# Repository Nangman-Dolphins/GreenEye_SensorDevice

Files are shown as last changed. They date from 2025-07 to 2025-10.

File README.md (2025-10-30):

# GreenEye 원예/화훼용 스마트 센서 단말기 (ESP32-CAM)

본 레포지토리는 ESP32-CAM을 기반으로 하는, 원예 및 화훼 환경 모니터링용 센서 단말기 펌웨어다. 이 장치는 화분이나 재배지의 환경 및 토양 데이터를 정밀하게 수집하고, 식물의 생장 상태 이미지를 촬영하여 MQTT 브로커를 통해 중앙 제어 장치(CCU)로 전송하도록 설계되었다. CCU로 전송된 데이터는 시계열 분석 및 인공지능(AI) 이미지 패턴 인식을 통해 식물의 현재 상태를 정밀하게 판단하고 관리하는 데 사용된다.

## 주요 기능

* **다중 센서 데이터 수집:**
    * **공중 환경:** 주변 온도, 습도 (AHT20)
    * **광량:** 작물 생장에 유효한 조도 (BH1750/GY-302)
    * **토양 상태:** 토양 온도, 토양 수분(함수율), 토양 전기 전도도(EC) (ADS1015 ADC 경유)
    * **장치 상태:** 배터리 잔량 (ADS1015 ADC 경유)
* **식물 생장 이미지 캡처:**
    * ESP32-CAM을 사용하여 설정된 주기(전원 모드별 상이)로 식물 이미지를 촬영하고, Base64로 인코딩하여 MQTT로 전송한다.
* **MQTT 양방향 통신:**
    * 수집된 모든 데이터를 JSON 형식으로 MQTT 브로커에 발행(publish)한다.
    * CCU로부터 설정 변경(전원 모드, 야간 모드 등) 및 실시간 데이터 요청 명령을 구독(subscribe)하여 원격으로 장치를 제어할 수 있다.
* **듀얼 모드 작동 (저전력/설정):**
    * **일반 모드 (Normal Mode):** 평상시 작동 모드. 설정된 주기에 따라 센서 측정, 데이터 전송 후 즉시 Deep Sleep 모드로 진입하여 배터리 소모를 최소화한다.
    * **설정 모드 (Setup Mode):** 장치 설치 시 사용하는 모드. WiFi AP로 동작하여 스마트폰 등으로 접속 가능한 웹 대시보드를 제공한다. WiFi 연결, CCU 주소 설정, 실시간 센서 값 확인, 카메라 스트리밍 등을 지원한다.
* **지능형 전원 관리:**
    * 6가지 상세 전원 모드를 지원하며, MQTT를 통해 원격으로 모드를 변경하여 데이터 수집 주기를 조절할 수 있다.
    * NTP 서버에서 시간을 동기화하여, 야간(21:00~06:00)에는 자동으로 측정을 중단하고 Deep Sleep을 유지하는 '야간 모드(Night Mode)'로 작동한다.

## 작동 모드 상세

이 펌웨어는 두 가지 명확히 구분된 모드로 작동한다.

### 1. 일반 모드 (Normal Mode)

* **진입:** 기본 작동 모드. Deep Sleep 상태에서 타이머에 의해 깨어나거나, 설정 모드에서 재부팅될 때 진입한다.
* **동작:**
    1.  Deep Sleep에서 깨어난다 (`bootCount` 1 증가).
    2.  `NetworkManager`가 `Preferences`에 저장된 WiFi 정보로 STA 모드 연결을 시도한다. (실패 시 설정 모드로 전환하기 위해 재부팅)
    3.  WiFi 연결 성공 시, `TimeManager`가 NTP 서버(pool.ntp.org, KST UTC+9)와 시간을 동기화한다.
    4.  `TimeManager`가 `isNightTime()` (21:00~06:00)을 확인한다.
        * **야간 모드일 경우:** `MQTT.loop()`만 짧게 실행하여 CCU의 명령(예: 모드 변경)을 수신한 뒤, `getSecondsUntil6AM()`으로 계산된 시간만큼 즉시 다시 Deep Sleep에 진입한다. (센서/카메라 작동 안 함)
        * **주간 모드일 경우:** 다음 5~9단계를 순차적으로 수행한다.
    5.  `MQTTClient`가 `Preferences`에 저장된 CCU 주소로 MQTT 브로커에 연결한다. (실패 시 설정 모드로 전환하기 위해 재부팅)
    6.  `sensors.readAllSensors()`를 호출하여 모든 센서 값을 읽어온다.
    7.  수집된 센서 데이터를 JSON으로 포맷하여 `GreenEye/data/[DeviceID]` 토픽으로 MQTT 발행한다.
    8.  `powerManager.shouldSendCameraData(bootCount)`를 호출, 현재 부팅 횟수가 카메라 전송 주기에 해당하는지 확인한다.
    9.  전송 주기가 맞다면, `camera.captureFrameForAnalyze()` (고화질)를 호출, 이미지를 Base64로 인코딩하여 `plant_img` 키와 함께 MQTT로 발행한다.
    10. `sensors.endI2C()`로 I2C 버스를 비활성화하고, `powerManager.enterDeepSleep()`을 호출하여 현재 전원 모드에 설정된 `_senseInterval` 시간만큼 Deep Sleep에 진입한다.

### 2. 설정 모드 (Setup Mode)

* **진입:**
    1.  장치가 Deep Sleep 상태(또는 전원이 꺼진 상태)일 때 `SETUP_BUTTON_PIN` (IO2) 버튼을 누른 상태로 전원을 켜거나 Deep Sleep에서 깨운다.
    2.  장치가 `ESP_SLEEP_WAKEUP_EXT0` (외부 핀) 인터럽트로 즉시 깨어난다.
    3.  `handleWakeupReason()` 함수가 이 웨이크업 사유를 감지하고, 비휘발성 메모리(Preferences)에 `setup_mode` 플래그를 `true`로 저장한 뒤, 장치를 **재부팅(ESP.restart())**한다.
    4.  재부팅된 장치의 `setup()` 함수가 `setup_mode` 플래그를 읽고 `isSetupMode = true`로 설정하여 설정 모드로 진입한다.
* **동작:**
    1.  `NetworkManager`가 `WIFI_AP_STA` 듀얼 모드로 작동한다.
        * **AP 모드:** `ge-sd-xxxx` (xxxx는 MAC 주소 하위 2바이트)라는 이름의 WiFi AP를 생성한다.
        * **STA 모드:** 동시에 `Preferences`에 저장된 기존 WiFi로 연결을 시도한다.
    2.  mDNS 서비스(`http://ge-sd-xxxx.local`)를 시작하여, AP에 연결된 기기가 이 주소로 쉽게 접속할 수 있게 한다.
    3.  `ESPAsyncWebServer`를 실행하여 `Webpages.h`에 정의된 웹 대시보드(HTML/CSS/JS)를 서비스한다.
    4.  **RTOS 태스크**를 생성하여 웹 서버와 다른 기능들이 병렬로 작동하게 한다. (Deep Sleep에 진입하지 않는다)
        * `backgroundTask` (Core 0): `MQTT.loop()`를 주기적으로 실행하고(WiFi STA가 연결된 경우), IO2 버튼을 3초 이상 누르면 설정 모드를 종료(플래그 삭제 및 재부팅)하는지 감지한다.
        * `cameraStreamTask` (Core 0): 웹 대시보드의 '카메라' 탭에서 WebSocket (`/ws`) 클라이언트가 연결되면, `camera.captureFrameForStream()` (저화질)을 통해 실시간 영상 스트림을 전송한다. 클라이언트가 없으면 `vTaskSuspend`로 작업을 중지시켜 자원을 아낀다.
* **종료:**
    1.  **(수동 종료)** IO2 버튼을 3초 이상 길게 누르면 `backgroundTask`가 이를 감지하여 `setup_mode` 플래그를 `false`로 바꾸고 재부팅한다.
    2.  **(자동 종료)** 웹 대시보드에서 WiFi 정보 또는 CCU 정보를 '저장'하거나 '삭제'하면, 해당 정보가 Preferences에 저장된 후 장치가 자동으로 재부팅된다. 재부팅 시 `setup_mode` 플래그가 없으므로 일반 모드로 시작한다.

## 레포지토리 구성 (파일 상세)

### 1. Arduino 펌웨어 (`.ino`, `.h`)

* **`SensorDevice_SW.ino`**:
    * **역할:** 메인 펌웨어 파일. 모든 클래스를 초기화하고 모드(일반/설정)에 따라 전체 동작 흐름을 제어한다.
    * **상세:**
        * `setup()`: `setup_mode` 플래그를 확인하여 **일반 모드** 또는 **설정 모드** 중 하나로 진입을 결정한다.
        * `loop()`: **일반 모드**에서는 센서 읽기, MQTT 전송, Deep Sleep의 순차적 로직을 수행한다. **설정 모드**에서는 아무 작업도 하지 않으며(모든 작업이 RTOS 태스크로 처리됨), `vTaskDelay`로 CPU를 양보한다.
        * **설정 모드**의 모든 웹 서버 라우팅(`server.on(...)`)과 WebSocket 이벤트 핸들러(`onWsEvent`)를 정의한다.
        * MQTT 콜백 함수(`handleDataRequest`, `handleConfig`)를 정의하여 CCU로부터의 원격 명령을 처리한다.

* **`Camera.h`**:
    * **역할:** ESP32-CAM (AI-Thinker 모델 기준)의 핀맵을 정의하고 카메라 센서(OV2640)를 초기화한다.
    * **상세:**
        * `captureFrameForStream()`: 웹소켓을 통한 실시간 스트리밍용. 저화질/고속(240x240, JPEG Quality 15) 프레임을 캡처한다.
        * `captureFrameForAnalyze()`: MQTT를 통해 CCU로 전송할 분석용. 고화질(240x240, JPEG Quality 3) 프레임을 캡처한다. (해상도는 동일하나 압축률이 낮아 화질이 좋다)

* **`SensorIO_withExtLibs.h`**: (현재 사용 중인 버전)
    * **역할:** 센서 관리를 위한 **외부 라이브B러리 기반** 클래스다.
    * **상세:** `Adafruit_ADS1X15`, `Adafruit_AHTX0`, `BH1750` 라이브러리를 사용한다. `begin()` 함수에서 각 라이브러리의 `begin()`을 호출하여 센서를 초기화하며, `read...()` 함수들이 라이브러리가 제공하는 API(예: `aht.getEvent()`, `lightMeter.readLightLevel()`)를 사용하여 값을 읽어온다. 개발 및 유지보수가 용이하다.

* **`SensorsIO.h`**: (대체/백업 버전)
    * **역할:** `SensorIO_withExtLibs.h`와 동일한 목적을 가지나, **외부 라이브러리 없이** `Wire.h`만을 사용하여 I2C 통신을 **직접 구현한** 클래스다.
    * **상세:** `readADS1015()`, `readAmbientTempHumi()` 등의 함수가 센서 데이터시트의 I2C 프로토콜(레지스터 주소, 설정값, 응답 바이트 파싱)을 직접 `Wire.write()`와 `Wire.requestFrom()`으로 구현한다. 라이브러리 의존성을 없애거나 메모리를 최적화할 때 사용될 수 있다.

* **`PowerManager.h`**:
    * **역할:** 장치의 전원 정책과 Deep Sleep 주기를 총괄한다.
    * **상세:**
        * `PowerMode` 열거형(enum)을 통해 6가지 전원 모드를 정의한다:
            * `ULTRA_LOW_POWER` (Z): 센서 2시간, 카메라 4시간
            * `LOW_POWER` (L): 센서 1시간, 카메라 2시간
            * `NORMAL` (M): 센서 30분, 카메라 1시간 (기본값)
            * `HIGH_FREQ` (H): 센서 20분, 카메라 1시간
            * `ULTRA_HIGH_FREQ` (U): 센서 20분, 카메라 40분
            * `DEBUGGING` (D): 센서 30초, 카메라 60초 (Deep Sleep 최소화, 테스트용)
        * `setMode(char modeChar)`: 외부(MQTT 또는 웹)에서 'Z', 'L' 등의 문자로 모드를 입력받아 `Preferences`에 저장한다.
        * `shouldSendCameraData(int bootCount)`: 현재 `bootCount`와 설정된 간격(`_senseInterval`, `_camInterval`)을 나누어, 나머지가 0일 때(즉, 카메라 주기가 도래했을 때) `true`를 반환한다.
        * `enterDeepSleep(unsigned long sleep_seconds)`: Deep Sleep 진입 전 `Wire.end()`로 I2C 버스를 종료하고, 타이머(시간) 및 `GPIO_NUM_2`(버튼)를 Wakeup 소스로 설정한 뒤 `esp_deep_sleep_start()`를 호출한다.

* **`MQTT.h`**:
    * **역할:** `PubSubClient` 라이브러리를 래핑하여 MQTT 통신을 안정적으로 관리한다.
    * **상세:**
        * 장치 MAC 주소 하위 2바이트로 고유 ID (예: `A1B2`)를 생성한다.
        * 3가지 토픽을 사용한다:
            * 발행(Pub): `GreenEye/data/[DeviceID]` (센서/이미지 데이터)
            * 구독(Sub): `GreenEye/req/[DeviceID]` (CCU의 데이터 즉시 전송 요청)
            * 구독(Sub): `GreenEye/conf/[DeviceID]` (CCU의 설정 변경 명령)
        * `reconnect()`: MQTT 브로커 연결을 시도하고, 실패 시 5회 재시도한다.
        * `onDataRequest`, `onConfig`: `SensorDevice_SW.ino`에 정의된 콜백 함수를 연결하여, 구독한 토픽에 메시지가 수신되면 해당 함수를 실행시킨다.

* **`NetworkManager.h`**:
    * **역할:** WiFi 연결(STA) 및 AP 모드를 관리한다.
    * **상세:** `begin()` 함수 하나로 `WIFI_AP_STA` 듀얼 모드를 시작한다. AP(`ge-sd-xxxx`)를 활성화하는 동시에 `Preferences`에 저장된 SSID로 STA 연결을 시도한다. 또한 `MDNS.begin()`을 호출하여 `http://ge-sd-xxxx.local` 주소로 웹 대시보드에 접속할 수 있도록 mDNS 서비스를 시작한다.

* **`TimeManager.h`**:
    * **역할:** NTP(Network Time Protocol)를 이용한 시간 동기화 및 야간/주간 판단을 담당한다.
    * **상세:**
        * `NTPClient`를 KST (UTC+9)로 초기화한다.
        * `isNightTime()`: 현재 시간이 21시(오후 9시)에서 6시(오전 6시) 사이인지 확인하여 야간 절전 모드 여부를 반환한다.
        * `getSecondsUntil6AM()`: 현재 시간이 야간일 때, 정확히 오전 6시(60초 버퍼 포함)에 깨어날 수 있도록 Deep Sleep에 필요한 총 시간(초)을 계산한다.

* **`Webpages.h`**:
    * **역할:** **설정 모드**에서 사용되는 모든 사용자 인터페이스(UI)의 HTML, CSS, JavaScript 코드를 `PROGMEM`을 통해 C++ 문자열 상수로 저장한다. (플래시 메모리에 저장하여 RAM을 절약)
    * **상세:**
        * `DASHBOARD_MAIN_TEMPLATE`: 모든 페이지의 기본 레이아웃 (헤더, 네비게이션 탭).
        * `SETUP_FORM_CONTENT` (루트 `/`, WiFi 미연결 시): WiFi SSID, PW, CCU 주소를 입력받는 폼. `/save`로 POST.
        * `DEVICE_STATUS_CONTENT` (루트 `/`, WiFi 연결 시): 현재 연결된 SSID와 CCU 주소를 보여주고 'WiFi 정보 삭제' 기능을 제공. `/forget`으로 POST.
        * `DASHBOARD_CONTENT` (`/dashboard`): `/api/sensors` 엔드포인트에 주기적으로 `fetch` 요청을 보내 실시간 센서 데이터를 JSON으로 받아와 표시한다.
        * `DEBUG_PAGE_CONTENT` (`/debug`): 수동 데이터 전송(`/send_sensor`), 전원 모드 변경(`/set_power_mode`), 야간 모드 활성화/비활성화(`/set_night_mode`)를 위한 폼을 제공한다.
        * `WEBSOCKET_CAMERA_PAGE_HTML` (`/camera`): 페이지 로드 시 `/ws` 주소로 WebSocket에 연결하고, 수신되는 바이너리(Blob) 이미지 데이터를 실시간으로 `<canvas>`에 그린다.

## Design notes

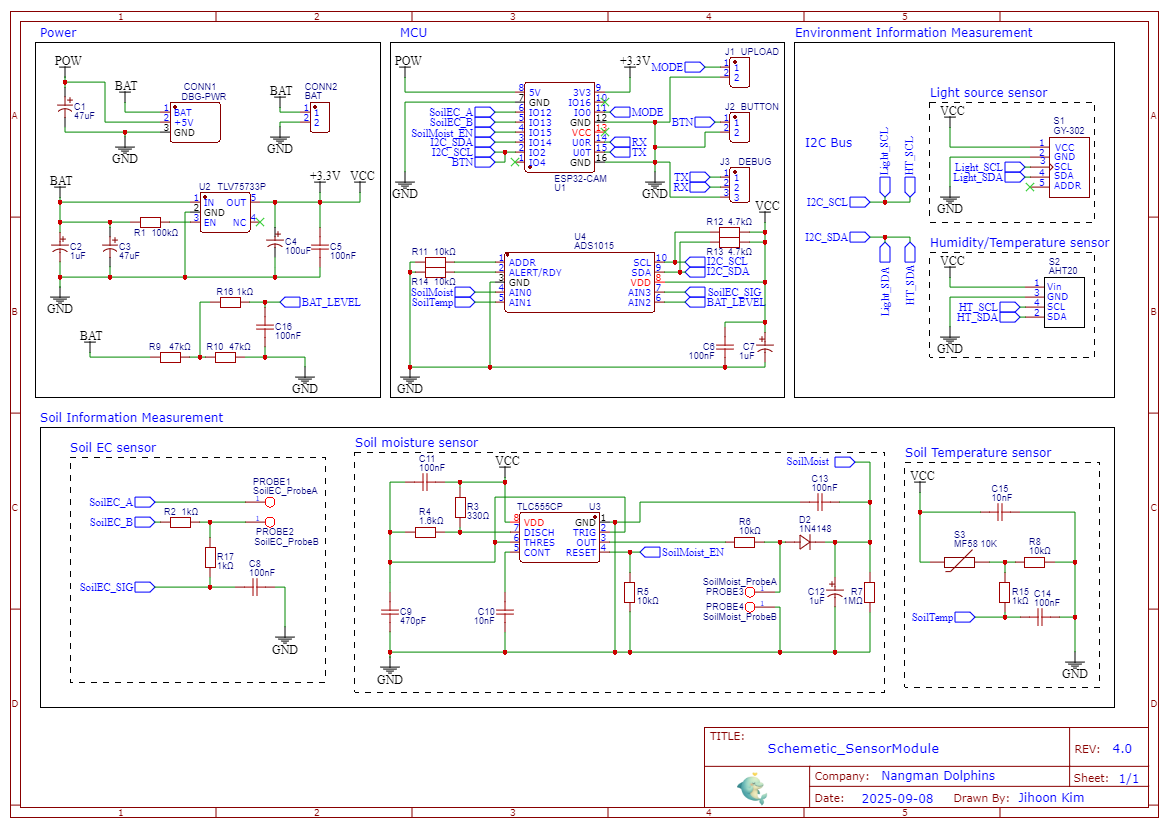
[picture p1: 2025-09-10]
Hardware/SizeReduction Version/Schemetic/Schematic_GreenEye_SensorModule.png

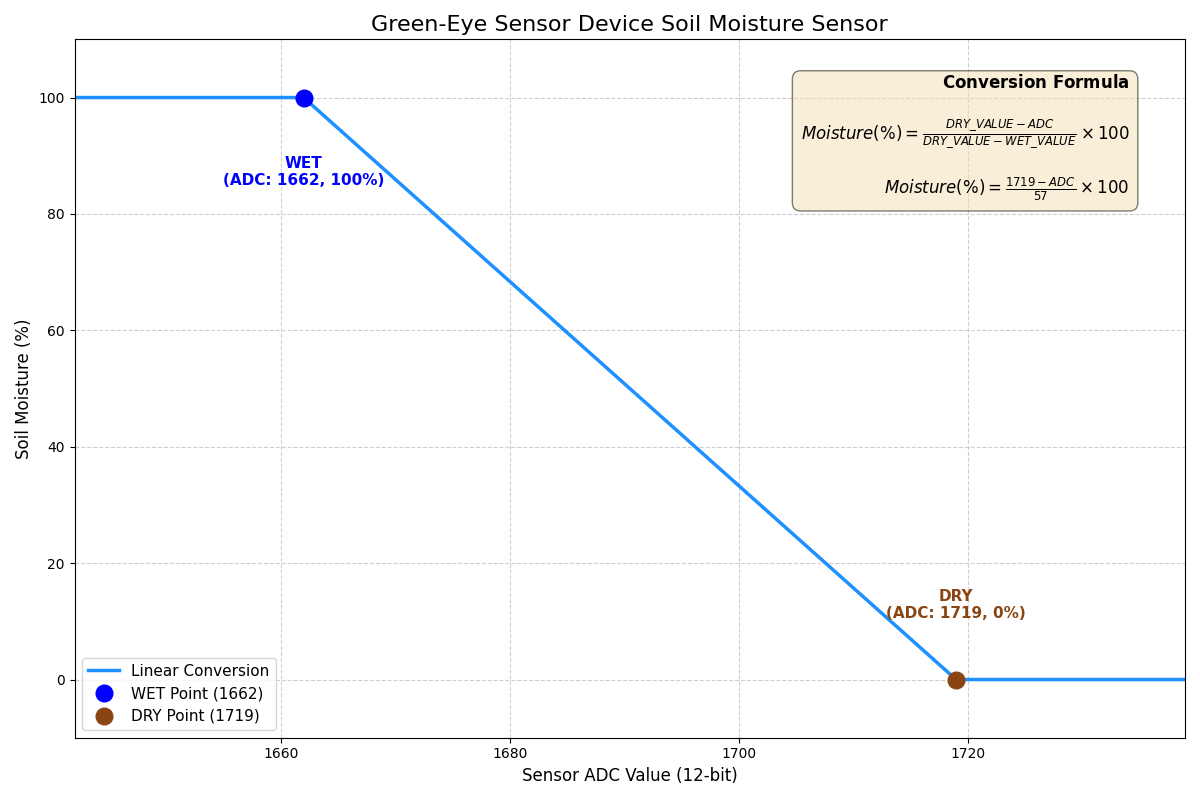
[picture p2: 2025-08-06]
Hardware/GreenEye Sensor Information/Soil Mositure Sensor/green-eye_soil_moisture_graph.png

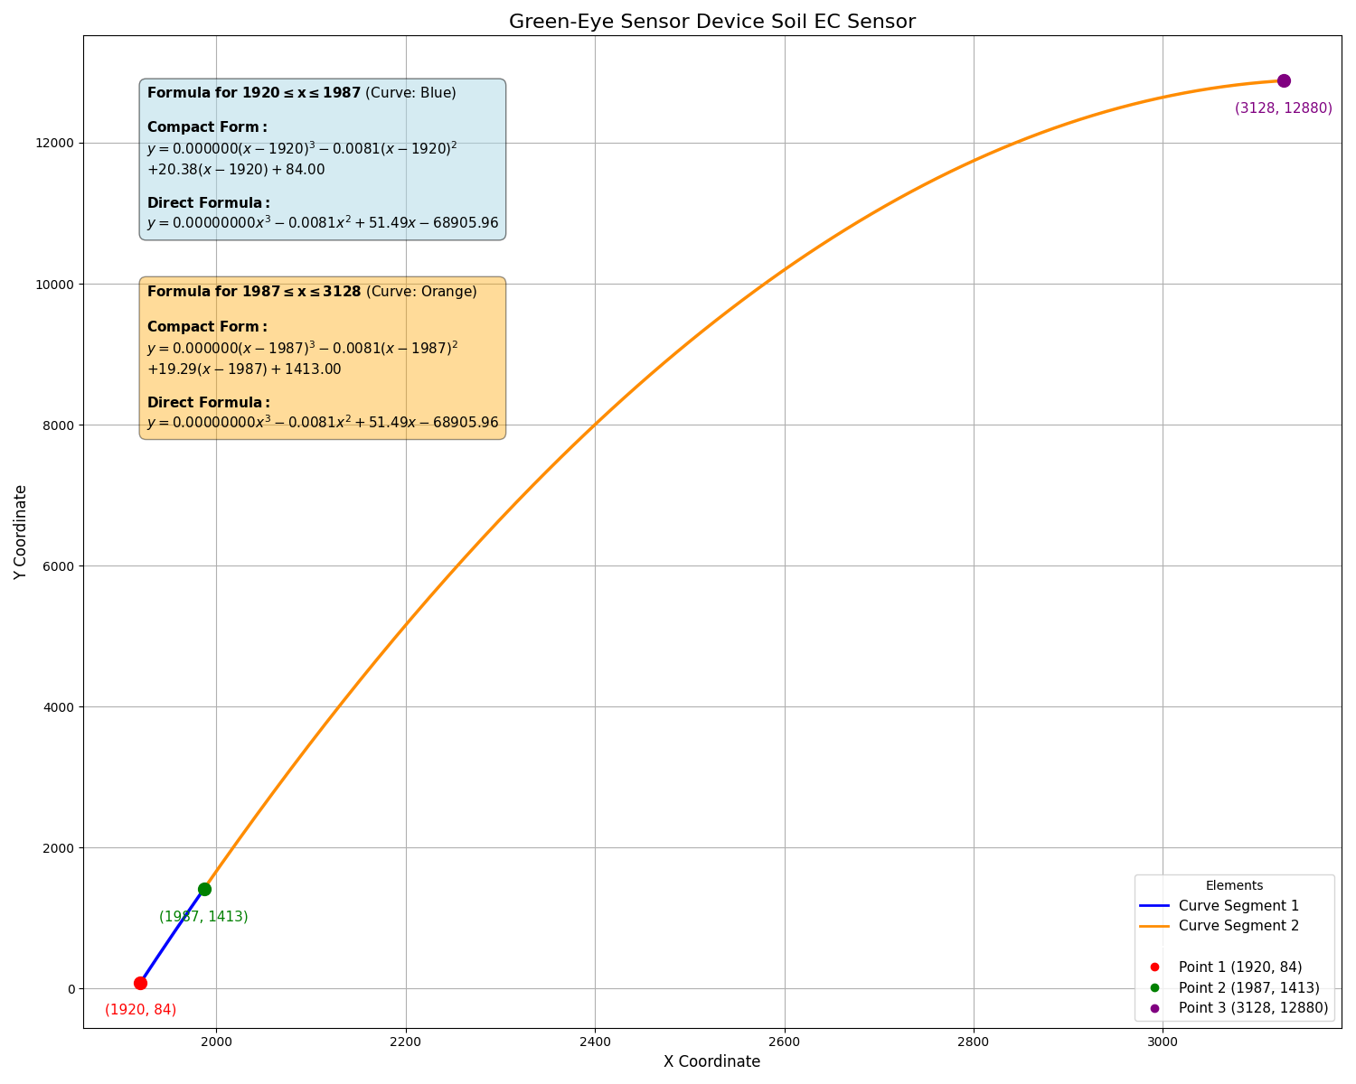
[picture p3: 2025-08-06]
Hardware/GreenEye Sensor Information/Soil EC Sensor/green-eye_soil_ec_graph.png

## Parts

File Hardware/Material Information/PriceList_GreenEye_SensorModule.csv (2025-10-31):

ID | 종류 | 이름 | 지정자 | 수량 | 가격 | 비고
1 | 캐패시터 | 10u | C1,C2 | 2 | \40 | 입력 전원 안정화
2 | 캐패시터 | 47u | C3 | 1 | \30 | LDO 레귤레이터-출력 전원 안정화
3 | 캐패시터 | 0.1u | C4,C5,C10,C11 | 4 | \40 | 로우패스
4 | 캐패시터 | 100n | C6 | 1 | \10 | 토양 수분 센서-타이머
5 | 캐패시터 | 470p | C7 | 1 | \10 | 토양 수분 센서-타이머
6 | 캐패시터 | 10n | C8 | 1 | \10 | 토양 수분 센서-타이머
7 | 캐패시터 | 1u | C9,C12 | 2 | \30 | 토양 수분 센서-Peak Dectector
8 | 다이오드 | 1N4148 | D1 | 1 | \10 | 토양 수분 센서-Peak Dectector
9 | 저항 | 100K | R1 | 1 | \10 | LDO 레귤레이터-Enable
10 | 저항 | 1K | R2 | 1 | \10 | 토양 전도도 센서-전압 분배 저항
11 | 저항 | 330 | R3 | 1 | \10 | 토양 수분 센서-타이머
12 | 저항 | 2.4K | R4 | 1 | \10 | 토양 수분 센서-타이머
13 | 저항 | 4.7K | R5 | 1 | \10 | 토양 수분 센서-타이머
14 | 저항 | 10K | R6,R7,R9,R10,R11,R12,R13 | 7 | \70 | R6: 토양수분센서-RC Filter R7: 토양수분센서-Reset 풀다운 저항 R9: 토양온도센서-전압 분배 저항 R10: I2C ADC 주소 설정 R11: I2C ADC 비교기 설정 R12,R13: I2C ADC 풀업 저항
15 | 저항 | 1M | R8 | 1 | \10 | 토양 수분 센서-Peak Dectector
16 | 센서 | GY-302 | S1 | 1 | \653 | 광도 센서
17 | 센서 | AHT20 | S2 | 1 | \1,200 | 온/습도 센서
18 | 센서 | NTC-100KGJG | S3 | 1 | \81 | 토양 온도 센서
19 | MCU | ESP32-CAM | U1 | 1 | \5,000 | MCU
20 | CAM | OV2940 |  |  | \4,000 | 식물 외형 정보
21 | 레귤레이터 | AP2112K-3.3 | U2 | 1 | \264 | 3.3V LDO 레귤레이터
22 | 타이머IC | TLC555CP | U3 | 1 | \188 | 토양 수분 센서-주파수 생성
23 | ADC | ADS1015 | U4 | 1 | \400 | 토양 센서 통합 통신
24 | PCB | PCB | - | 1 | \1,880 | 메인 보드 (5개 생산 기준)
25 | 기구 | etc | - | 1 | \2,000 | 필라멘트 100m
26 | 전원 | Li-po 1,800mAh | - | 1 | \3,500 | 전원공급
 |  |  |  | 총 가격 | \19,476

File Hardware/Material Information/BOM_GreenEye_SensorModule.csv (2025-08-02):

ID | Name | Designator | Quantity
1 | GY-302 | S1 | 1
2 | AHT20 | S2 | 1
3 | MF58 10K | S3 | 1
4 | ESP32-CAM | U1 | 1
5 | AP2112K-3.3 | U2 | 1
6 | TLC555CP | U3 | 1
7 | ADS1015 | U4 | 1
8 | 10u | C1,C2 | 2
9 | 47u | C3 | 1
10 | 0.1u | C4,C5,C10,C11 | 4
11 | 100n | C6 | 1
12 | 470p | C7 | 1
13 | 10n | C8 | 1
14 | 1u | C9,C12 | 2
15 | 100K | R1 | 1
16 | 1K | R2 | 1
17 | 330 | R3 | 1
18 | 2.4K | R4 | 1
19 | 4.7K | R5 | 1
20 | 10K | R6,R7,R9,R10,R11,R12,R13 | 7
21 | 1M | R8 | 1
22 | 470K | R14,R15 | 2
23 | 1N4148 | D1 | 1

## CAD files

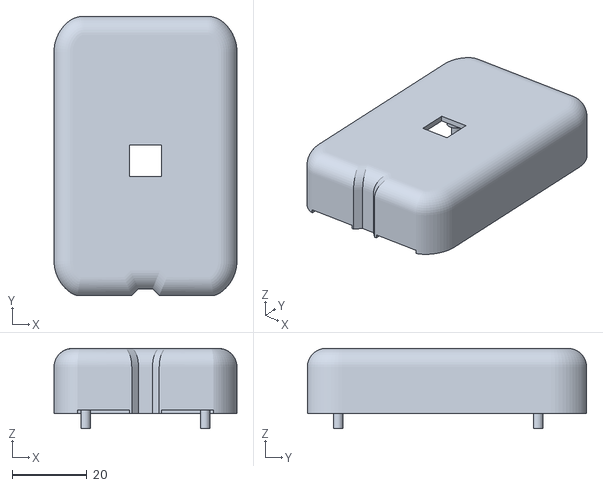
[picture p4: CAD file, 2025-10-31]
Hardware/SizeReduction Version/Case/Front Cover.stl
49.0 x 74.8 x 21.5

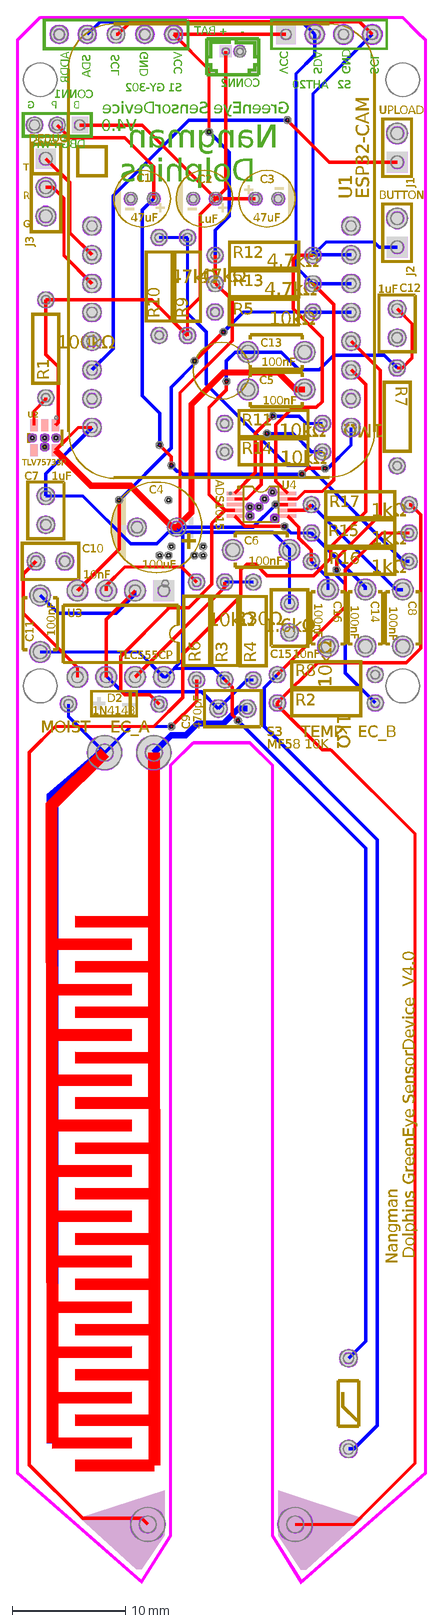
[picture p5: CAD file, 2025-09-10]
Hardware/SizeReduction Version/PCB/PCB_GreenEye_SensorModule.dxf
GreenEye SensorDevice
Nangman
Dolphins
-
+
VCC
GND
SCL
SDA
G
P
B
V4.0
EC_B
TEMP
T
R
EC_A
MOIST
BAT
CONN2
AHT20
S2
DBG-PWR
CONN1
1kΩ
R16
R17
100nF
C14
C16
10nF
C15
R15
100kΩ
R1
R2
330Ω
R3
1.6kΩ
R4
10kΩ
R5
R6
1MΩ
R7
R8
47kΩ
R9
R10
R11
4.7kΩ
R12
R13
R14
100uF
C4
1uF
C7
C12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

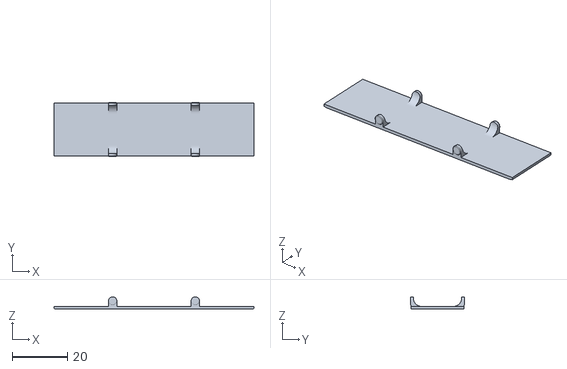
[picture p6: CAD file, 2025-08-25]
Hardware/Standard Version/Case/Top Bat Cover.stl
72.6 x 19.7 x 4.49

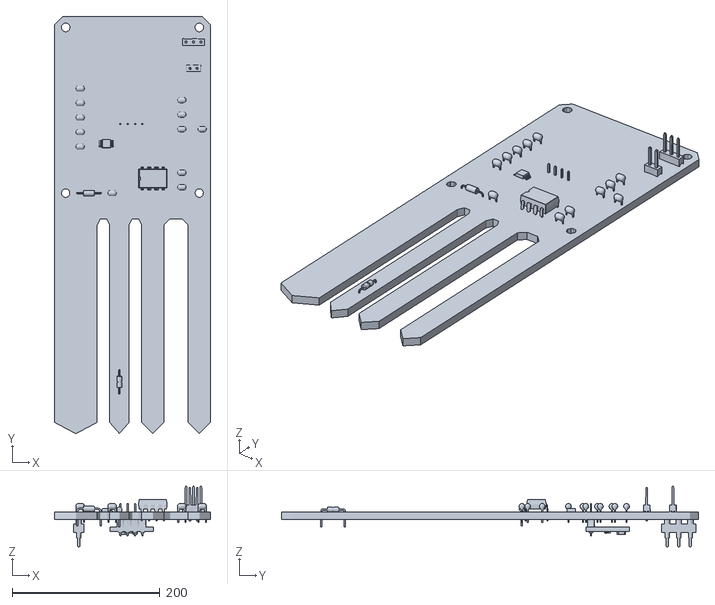
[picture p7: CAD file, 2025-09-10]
Hardware/Standard Version/PCB/3D/OBJ_PCB_GreenEye_SensorModule.obj
211.4 x 565.6 x 82.4

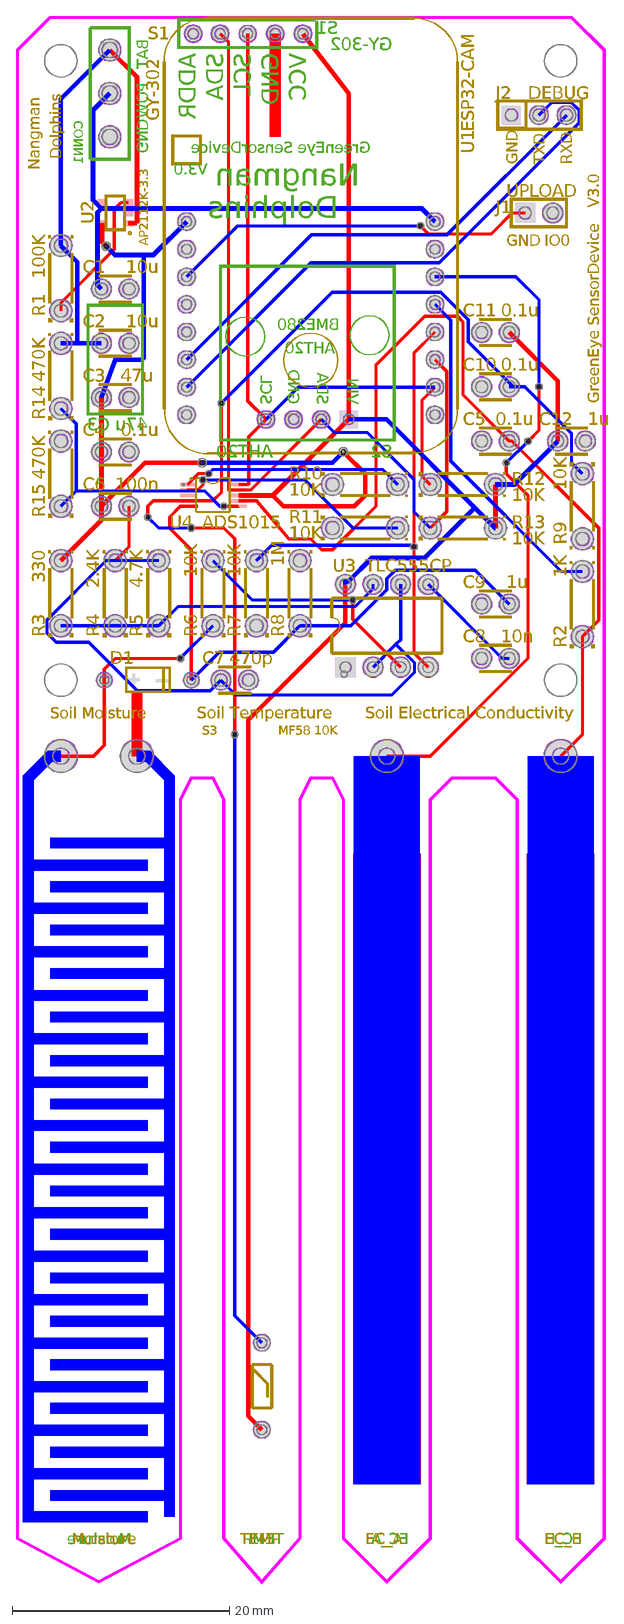
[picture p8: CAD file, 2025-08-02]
Hardware/Standard Version/PCB/PCB_GreenEye_SensorModule.dxf
GreenEye SensorDevice
V3.0
BAT
POW
GND
S1
GY-302
Moisture
EC_B
EC_A
TEMP
Soil Moisture
Soil Electrical Conductivity
Soil Temperature
TXD
RXD
IO0
Dolphins
Nangman
47u
C3
VCC
SCL
SDA
ADDR
AP2112K-3.3
U2
AHT20
S2
VIN
BME280
CONN1
ESP32-CAM
U1
10u
C1
C2
0.1u
C4
C5
100n
C6
470p
C7
10n
C8
1u
C9
C10
C11
C12
100K
R1
1K
R2
330
R3
2.4K
R4
4.7K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

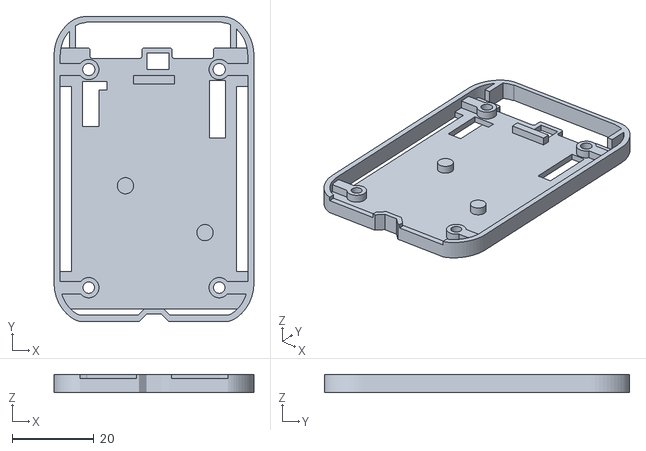
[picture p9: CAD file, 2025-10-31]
Hardware/SizeReduction Version/Case/Mid Plate.stl
49.0 x 74.8 x 4.50

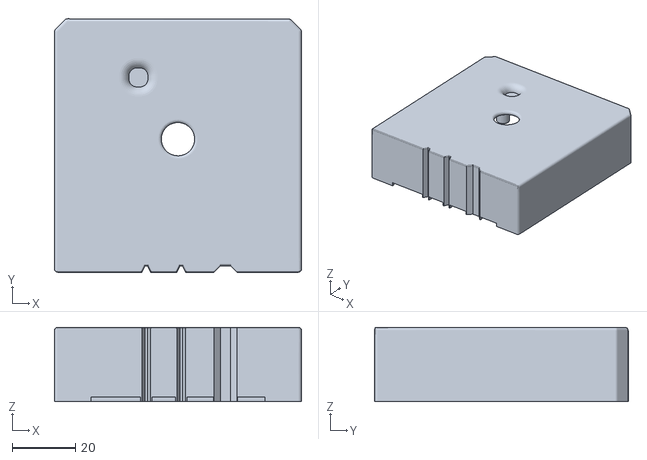
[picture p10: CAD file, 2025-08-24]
Hardware/Standard Version/Case/Front Cover.stl
78.0 x 80.1 x 23.5

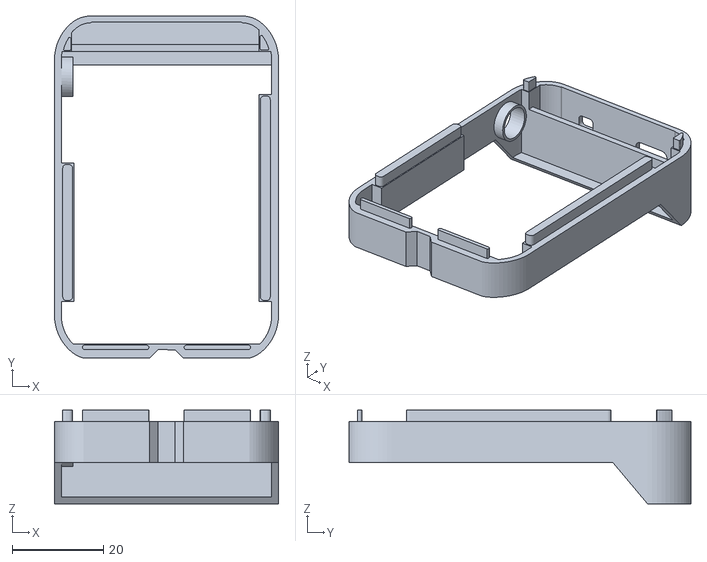
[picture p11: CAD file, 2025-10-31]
Hardware/SizeReduction Version/Case/Rear Cover.stl
49.0 x 74.8 x 20.5

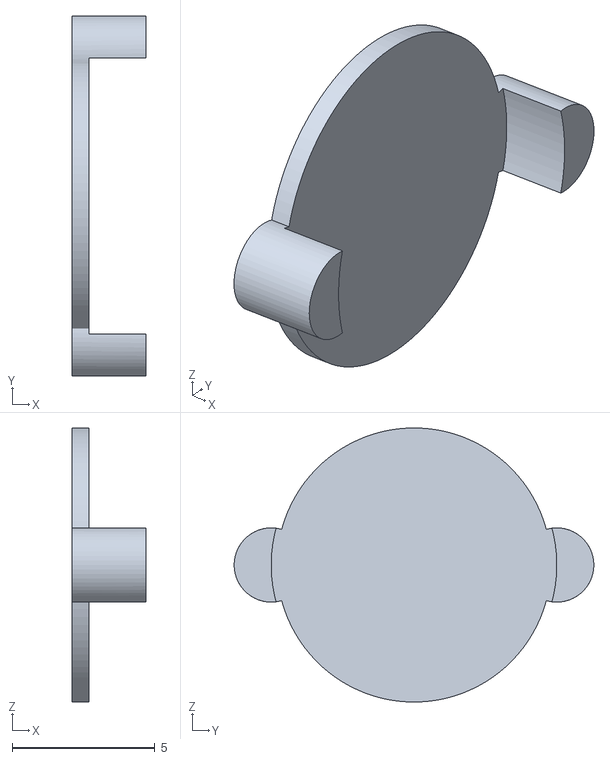
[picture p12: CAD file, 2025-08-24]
Hardware/Standard Version/Case/Side Bat Cover.stl
2.60 x 12.6 x 9.60

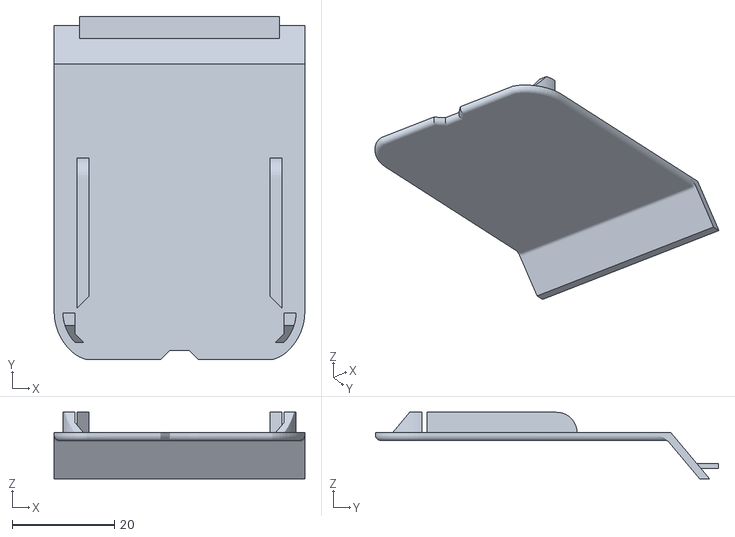
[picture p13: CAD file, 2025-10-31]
Hardware/SizeReduction Version/Case/Bat Cover.stl
49.0 x 67.0 x 13.0

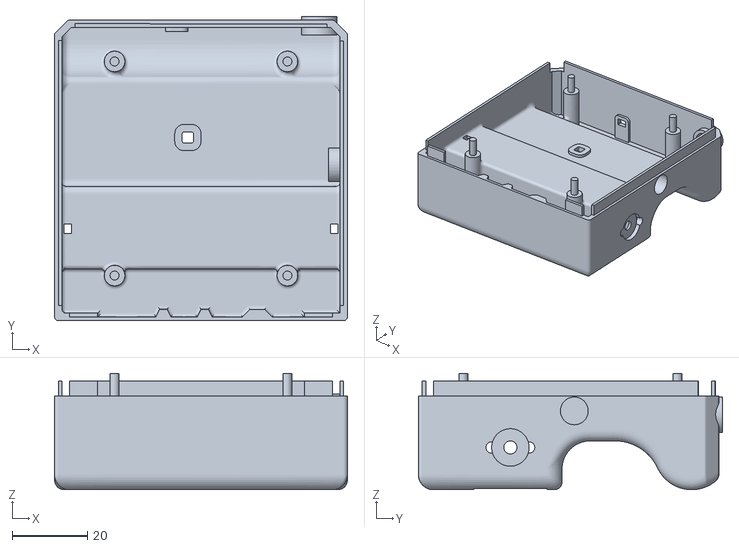
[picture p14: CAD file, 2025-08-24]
Hardware/Standard Version/Case/Back Cover.stl
78.0 x 81.0 x 31.0

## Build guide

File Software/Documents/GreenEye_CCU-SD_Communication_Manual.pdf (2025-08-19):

2025-08-16, jihoonkimtech, softyware21

페이지 1/3

## GreenEye CCU-SD Communication Manual

센서 단말(SD)과 중앙 제어 유닛(CCU)은 MQTT 프로토콜을 통해 통신한다.

### 1. Base Setting

CCU와 SD가 서로 같은 AP에 연결되어 있다는 가정 하에 다음과 같이 설정한다.

센서 단말

Device ID | {장치의 MAC 최하위 4자리}
IP | DHCP (유동 IP)
DNS | ge-sd-{Device ID}.local
Port | 1883

중앙 제어 유닛

Device ID | {장치의 MAC 최하위 4자리}
IP | DHCP (유동 IP)
DNS | ge-ccu-{Device ID}.local
Port | 1883

SD에서 장치 설정을 통해 CCU의 DNS를 입력받아 저장하고, 매 통신마다 입력받은 DNS와 지정

된 Port 번호를 통해 CCU의 MQTT Broker(Mosquitto)에 연결한다.

### 2. Topics

연결된 두 장치는 아래와 같은 Topic을 사용해 데이터를 송수신한다.

Topic | 설명 | 발행자 | 구독자
GreenEye/data/{SD의 Device ID} | 센서 및 이미지 데이터 송수신 | SD | CCU
GreenEye/req/{SD의 Device ID} | 데이터 요청 송수신 | CCU | SD
GreenEye/conf/{SD의 Device ID} | 단말 설정 데이터 송수신 | CCU | SD

페이지 2/3

### 3. Data format

Topic을 통해 오가는 데이터는 Json 형태로 하며, 각 장치에서 Parsing하여 사용토록 한다.

센서 및 이미지 데이터 (GreenEye/data/*)

Key | Value | data type | data unit
bat_level | 단말의 전원 정보 | int | %
amb_temp | 단말 주변 환경의 온도 | float | °C
amb_humi | 단말 주변 환경의 습도 | float | %
amb_light | 단말 주변 환경의 광도 | float | lux
soil_temp | 단말이 꽂힌 토양의 온도 | float | °C
soil_humi | 단말이 꽂힌 토양의 수분 포화도 | float | %
soil_ec | 단말이 꽂힌 토양의 전기 전도도 | float | uS/cm
plant_img | 단말이 촬영한 식물의 형태 정보 | frame buffer (HEX) | jpeg

해당 데이터는 SD가 CCU로부터 데이터 요청 송수신을 받았을 경우에만 CCU로 송신한다.

데이터 요청 송수신 (GreenEye/req/*)

Key | Value | data type | mean
req | 송신 요청 데이터 지정 | boolean | 1 for sensor only 0 for full request

해당 데이터는 사용자 설정에 의해 특정 주기마다 CCU가 SD로 송신한다. (디버깅용)

단말 설정 데이터 송수신 (GreenEye/conf/*)

Key | Value | data type | mean
pwr_mode | 배터리 모드 설정 | char | ‘Z’,‘L’,‘M’,‘H’,‘U’
nht_mode | 야간 모드 활성화 여부 | boolean | 0 for disable 1 for enable
flash_en | 상시 플래시 활성화 여부 | boolean
flash_nt | 야간 촬영시 플래시 활성화 여부 | boolean
flash_level | 플래시의 밝기 | int | max = 255

해당 데이터는 사용자가 CCU로부터 SD의 세부 설정을 변경할 경우의 상세 설정 정보를 담아 SD

로 송신하게 된다.

페이지 3/3

### 4. Security

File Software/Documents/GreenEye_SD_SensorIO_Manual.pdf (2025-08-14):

2025-08-14, jihoonkimtech

페이지 1 / 6

## Green-Eye Sensor Device Sensor I/O Manual

### 1. Connection

GreenEye Sensor Device(이하 SD)의 모든 Sensor는 I

2C 프로토콜로 통신된다.

ESP32-CAM (MCU)

주소 | -
전압 레벨 | 3.3V
핀 명 | 할당 역할 | 연결
IO14 | SDA Master | Slave’s SDA
IO2 | SCL Master | Slave’s SCL
IO15 | Soil Moisture Sensor Enable Trigger | Soil Moisture’s Reset
IO12 | Soil EC Probe Current Direction Control | Soil EC Probe A
IO13 | | Soil EC Probe B
MCU인 ESP32이 I

2C Master가 되며 통신 핀으로 각각 IO14(SDA), IO2(SCL)를 사용한다.

추가로 Soil Moisture Sensor의 활성화를 위해 IO15 핀을 사용한다. (Enable to HIGH). Soil

### EC 측정 시, 분극 효과를 방지하기 위해 측정 시에만 Active 되게 하고, 양 프로브에 가

해질 전압을 계속 번갈아 Switching 하기 위해서 IO12, IO13 핀을 사용한다.

AHT20 (Ambient Humidity/Temperature Sensor)

주소 | 0x38 (default)
전압 레벨 | 3.3V
핀 명 | 할당 역할 | 연결
SDA | SDA Slave | Master’s SDA
SCL | SCL Slave | Master’s SCL

GY-302 (Ambient Light source Sensor)

주소 | 0x23 (default)
전압 레벨 | 3.3V
핀 명 | 할당 역할 | 연결
SDA | SDA Slave | Master’s SDA
SCL | SCL Slave | Master’s SCL

### 환경 습도/온도를 측정하기 위한 AHT20와 환경 광도를 측정하기 위한 GY-302의 경우

### 내장된 I

2C IC를 사용하여 직접 MCU의 SDA, SCK와 연결한다.

ADS1015 (External 12bit ADC for Soil Sensors)

주소 | 0x48 (by setting)
전압 레벨 | 3.3V
핀 명 | 할당 역할 | 연결
SDA | SDA Slave | Master’s SDA
SCL | SCL Slave | Master’s SCL
AIN0 | Analog Input 0 | Soil Temperature’s signal
AIN1 | Analog Input 1 | Soil Moisture’s signal
AIN2 | Analog Input 2 | Battery level
AIN3 | Analog Input 3 | Soil EC’s signal

### 토양 센서의 대부분이 아날로그 출력을 갖는다. 배터리 측정 또한 전압 분배 회로를 통

### 해 낮춘 배터리의 전압을 아날로그로 측정한다. 여기서 내장 ADC를 사용하지 않는 이유

는 ESP32 사용시 WiFi/BT를 활성화하면 ADC2 채널이 간섭받기 때문에 외장 ADC를 채 용하여 사용한다.

### 2. Communication Rules & Usage

### 각 센서 별로 I

### 2C 통신을 통해 데이터가 어떤 형식으로 MCU에 전달되는 지 정리하고

SD에서는 어떻게 설정되어 사용할 것인지 기술한다.

AHT20

신호 구분 | 명령어 | 데이터 | 동작
쓰기 | 0xBE | - | 초기화, 보정 계수 로드
쓰기 | 0xAC | 0x33, 0x00 | 측정 시작, 75ms 소요
읽기 | | | 상태+습도+온도+CRC Master로 반환

### 읽기 신호를 보낸 뒤 받아지는 데이터는 총 7 byte로, 최상단 상태 1byte와 최하단 CRC

1byte를 제외한 사이 5byte가 실제 습도, 온도 데이터이다.

[0] | [1] | [2] | [3] | [4] | [5] | [6]
상태 | 습도 상위 | 습도 중간 | 습도 하위 | 온도 상위 | 온도 중간 | 온도 하위 | CRC
| SRH | ST
데이터에서 습도와 온도 데이터 비트를 Parsing해 아래와 같은 공식에 대입해 사용한다.

GY-302

신호 구분 | 명령어 | 데이터 | 동작
쓰기 | 0x00 | - | 저전력 모드 활성화
쓰기 | 0x01 | - | 저전력 모드 비활성화
쓰기 | 0x07 | | 초기화, 측정 중단
쓰기 | 0x10 | - | 연속 고해상도 1(해상도 1 lux) 모드 설정, 120ms 소요
쓰기 | 0x11 | - | 연속 고해상도 2(해상도 0.5 lux) 모드 설정, 120ms 소요
쓰기 | 0x13 | - | 연속 저해상도 (해상도 4lux) 모드 설정, 16ms 소요
쓰기 | 0x20 | | 1회 고해상도 1, 120ms 소요, 이후 저전력
쓰기 | 0x21 | | 1회 고해상도 2, 120ms 소요, 이후 저전력
쓰기 | 0x23 | | 1회 저해상도, 16ms 소요, 이후 저전력
읽기 | | | 조도 데이터 Master로 반환
읽기 신호를 통해 받아지는 데이터는 총 2byte로 별도의 데이터 없어 전체가 광도 값이다. 수신

한 데이터를 16bit integer로 결합한 후 사용한다. SD에서는 전력 효율을 위해 1회 고해상도 1 모

드를 사용하여 n회 측정한 뒤, 평균 값을 내어 사용한다.

[0] [1]
조도 상위 | 조도 하위

SI
이 데이터를 데이터시트 상에서 제시하는 보정 값 1.2를 활용하여 다음과 같이 계산해 산출한다.

ADS1015

신호 구분 | 명령어 | 데이터 | 동작
쓰기 | 0x01 | 2byte 설정 데이터 | 설정 레지스터 변경, 채널 선택|범위 지정|모드 선택
쓰기 | 0x00 | - | 변환 레지스터 참조 지정.
읽기 | | | 변환된 데이터 Master로 반환
명령어는 포인터 레지스터로 Master와 연결되는 레지스터를 지정한다. 쓰기 신호에서 명령어

0x01을 통해 설정 레지스터와 연결하고, 데이터를 보내 ADC 설정을 완료한다. 이후 변환이 시작

되면 변환 레지스터로 값이 기록되게 된다. 값을 읽기 위해선 쓰기 신호 명령어 0x00을 보내어

변환 레지스터와 연결하고 읽기 신호를 보내면 변환 레지스터의 값이 받아지게 된다.

15 | 14-12 | 11-9 | 8 | 7-5 | 4-0
OS | MUX | PGA | MODE | DR | COMP
시작 트리거 | 채널 선택 | 게인 설정 | 측정 모드 | 초당 변환 횟수 | 비교기 설정
설정 비트의 구성은 위와 같으며, 비트에 대한 상태 정보는 아래와 같다.

OS
0: 효과 없음 (Default) | 1: 단일 변환 시작 트리거
OS 비트는 단일 변환 모드의 경우 변환 시작의 트리거가 되는 비트이다.

MUX
0xx: AINxx와 AIN1(00일 경우) 또는 AIN3와 차동 측정 | 1xx: AINxx의 단일 종단 측정
MUX 비트는 채널을 선택하기 위해 사용하며 SD 에서는 단일 종단 측정만을 사용한다.

PGA

값 | 범위 | 해상도(PGAResolution)
000 | ±6.144V | 3mV
001 | ±4.096V | 2mV
010 | ±2.048V | 1mV
011 | ±1.024V | 0.5mV
100 | ±0.512V | 0.25mV
101 | ±0.256V | 0.125mV
PGA는 측정 범위를 설정하는데 쓰이며, Soil Sensor의 최대 전압이 3.3V이므로 ±4.096V 범위를 지

정하여 사용한다.

MODE
0: 연속 변환 | 1: 단일 변환, 이후 저전력 모드
측정 모드를 설정하는 비트이며, SD에서는 전력 효율을 위해 단일 변환 모드로 n회 측정하여 값

을 누적한 뒤 평균을 내어 사용한다.

DR
값 | SPS (Samples Per Second)
000 | 128
001 | 250
010 | 490
011 | 920

100 1600

101 | 2400
110 | 3300
DR은 1초에 얼마만큼의 샘플을 변환할지 결정하며 SD에서는 안정적인 기본값 1600을 선택하여

사용한다.

COMP
0011: 비활성화
COMP는 비교기의 활성화 여부를 결정 짓는데 쓰이며 SD에서는 비교기를 사용하지 않기 때문에

항상 비활성화 상태로 둔다.

[0] [1]
변환 값 상위 | 변환 값 하위

ADCRAW
변환되는 데이터 형식은 위와 같다. 여기서 변환 값은 12bit 이므로 하위 4bit는 0으로 채워진다.

실제 사용시에는 >>4 연산 이후에 사용한다. Raw 값이 아닌 전압 형태로 사용하고자 한다면 아

래와 같은 공식을 이용하여 산출한다.

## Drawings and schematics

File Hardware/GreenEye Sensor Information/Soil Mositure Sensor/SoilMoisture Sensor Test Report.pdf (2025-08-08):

SoilMoisture Sensor Test Report | Report

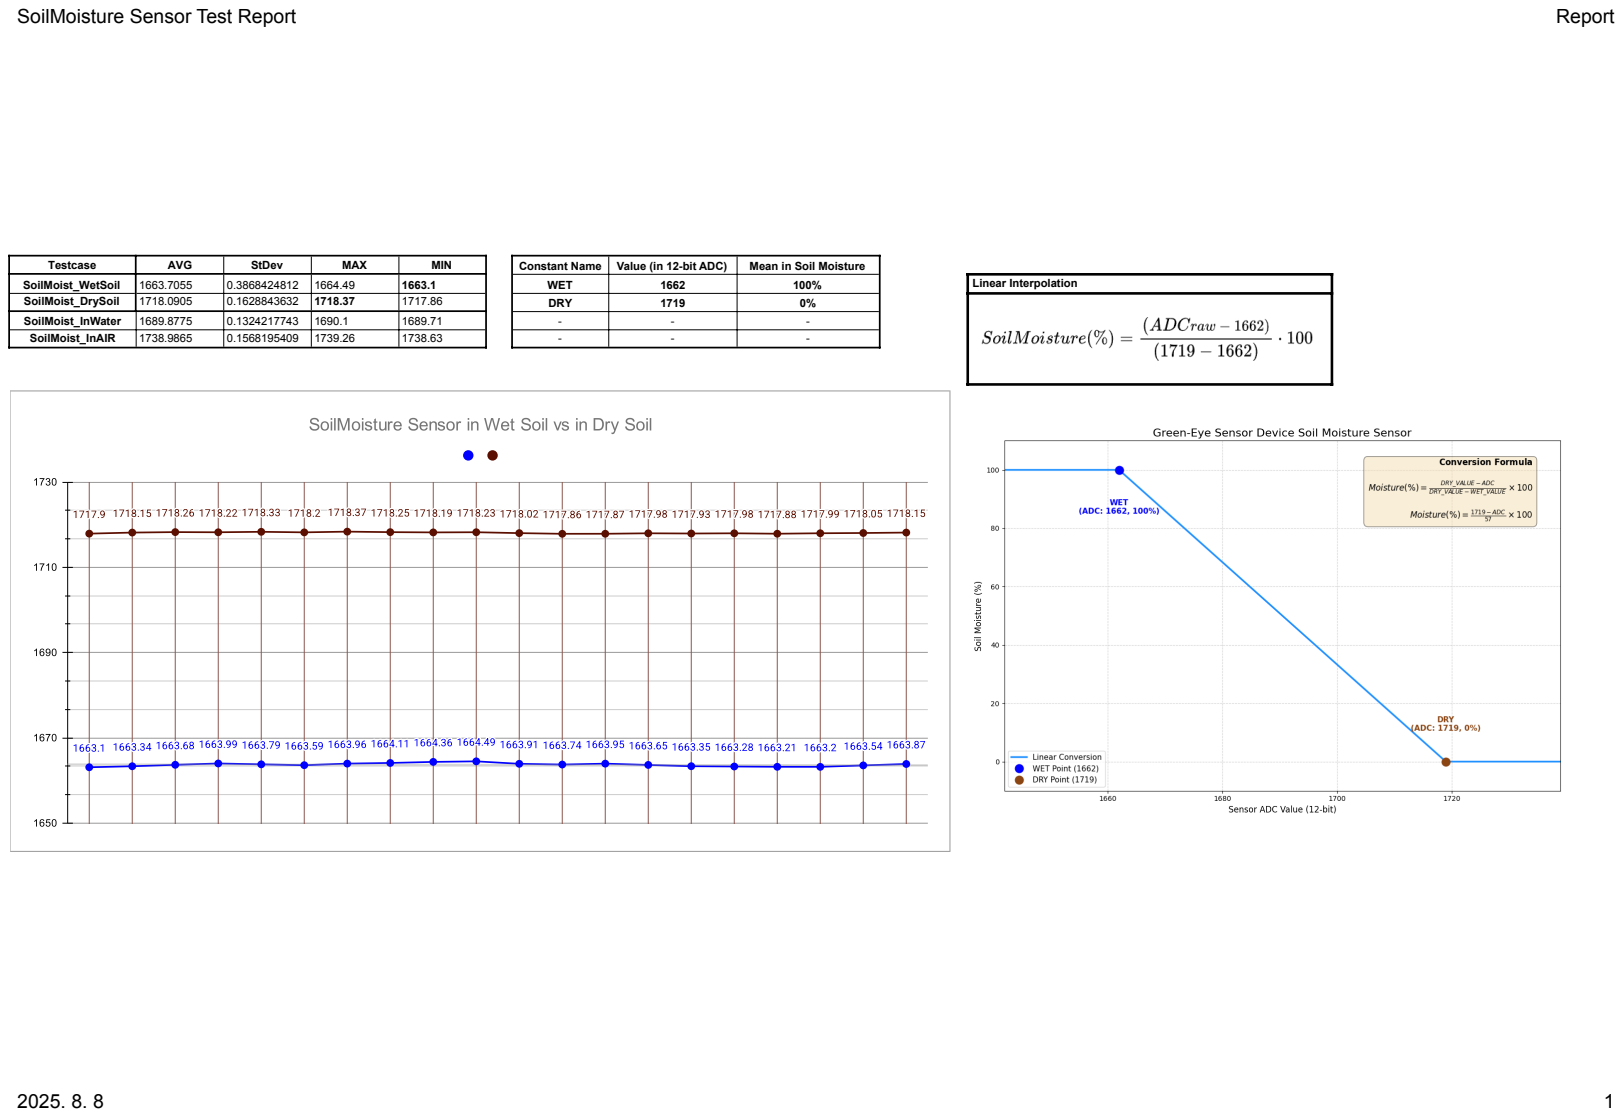
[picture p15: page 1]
Testcase; AVG; StDev; MAX; MIN; Constant Name; Value (in 12-bit ADC); Mean in Soil Moisture; SoilMoist_WetSoil; WET; Linear Interpolation; SoilMoist_DrySoil; DRY; SoilMoist_InWater; SoilMoist_InAIR

SoilMoisture Sensor Test Report | SoilMoist_WetSoil

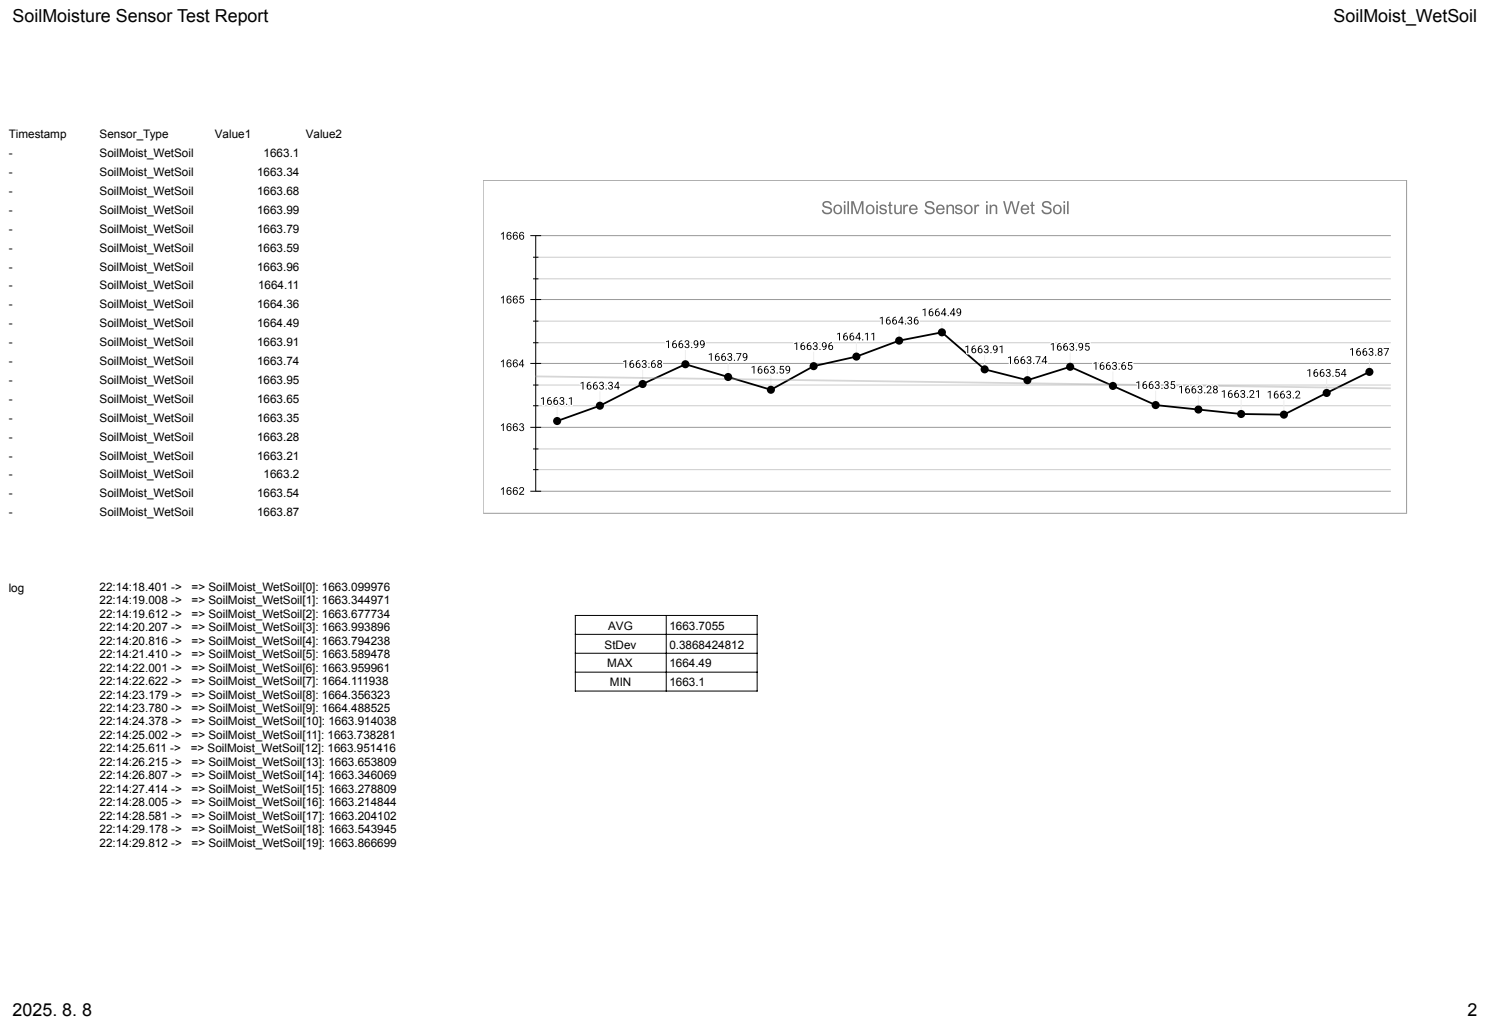
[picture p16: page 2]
Timestamp; Sensor_Type; Value1; Value2 -; SoilMoist_WetSoil; log; 22:14:18.401 -> => SoilMoist_WetSoil[0]: 1663.099976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

AVG | 1663.7055
StDev | 0.3868424812
MAX | 1664.49
MIN | 1663.1

SoilMoisture Sensor Test Report | SoilMoist_DrySoil

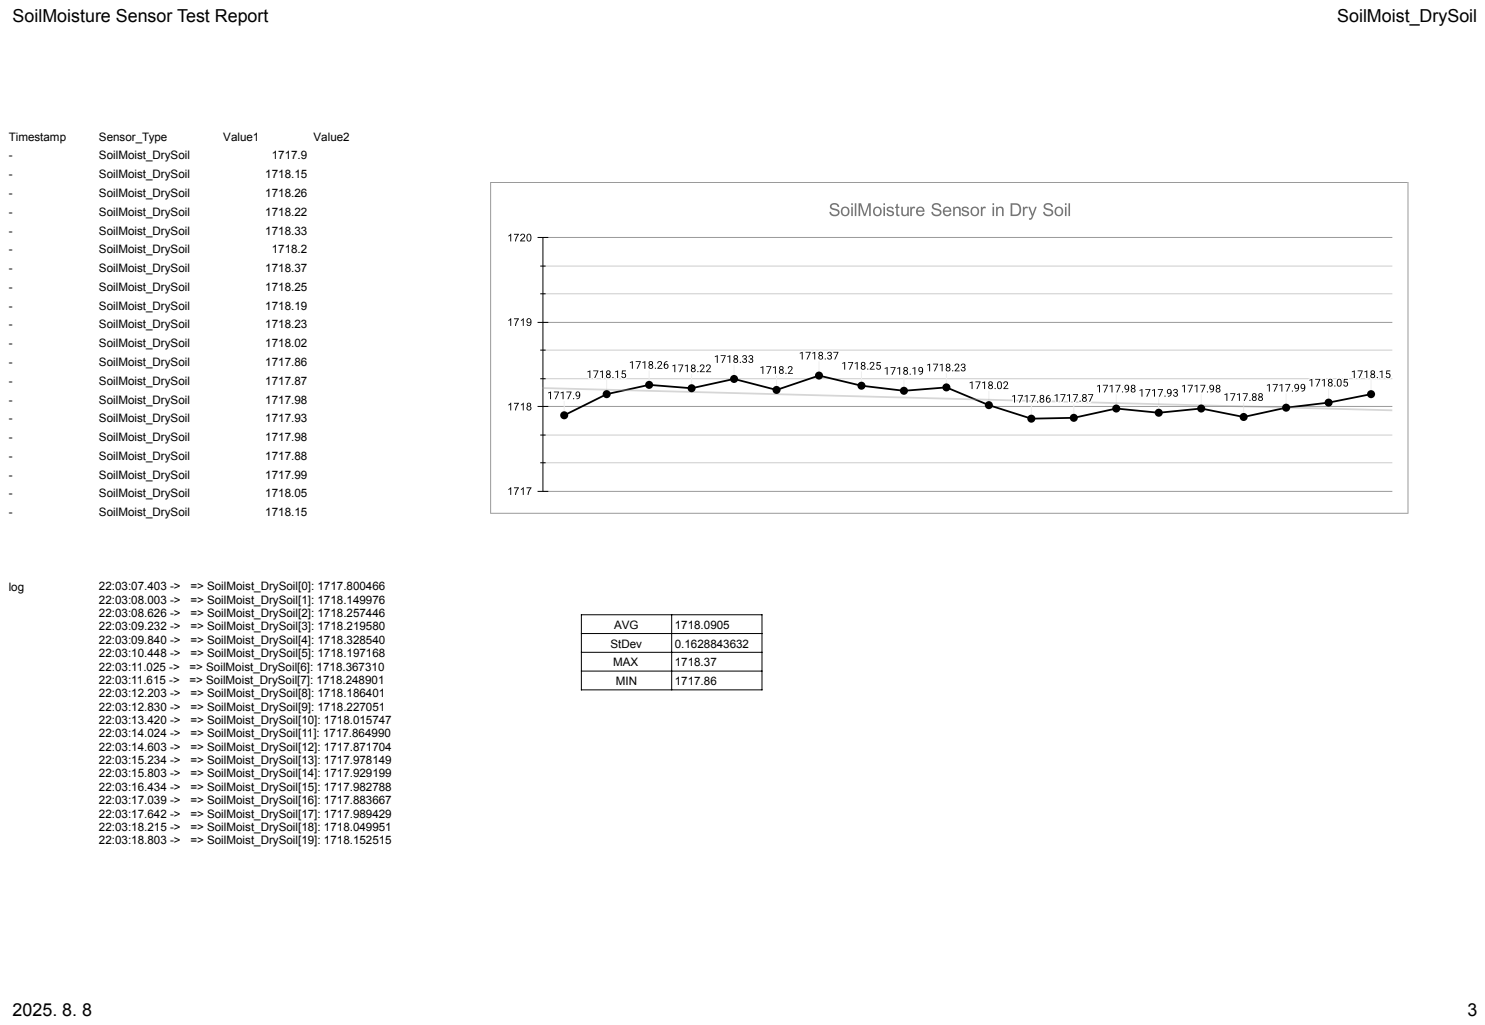
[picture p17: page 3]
Timestamp; Sensor_Type; Value1; Value2 -; SoilMoist_DrySoil; log; 22:03:07.403 -> => SoilMoist_DrySoil[0]: 1717.800466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

AVG | 1718.0905
StDev | 0.1628843632
MAX | 1718.37
MIN | 1717.86

SoilMoisture Sensor Test Report | SoilMoist_InWater

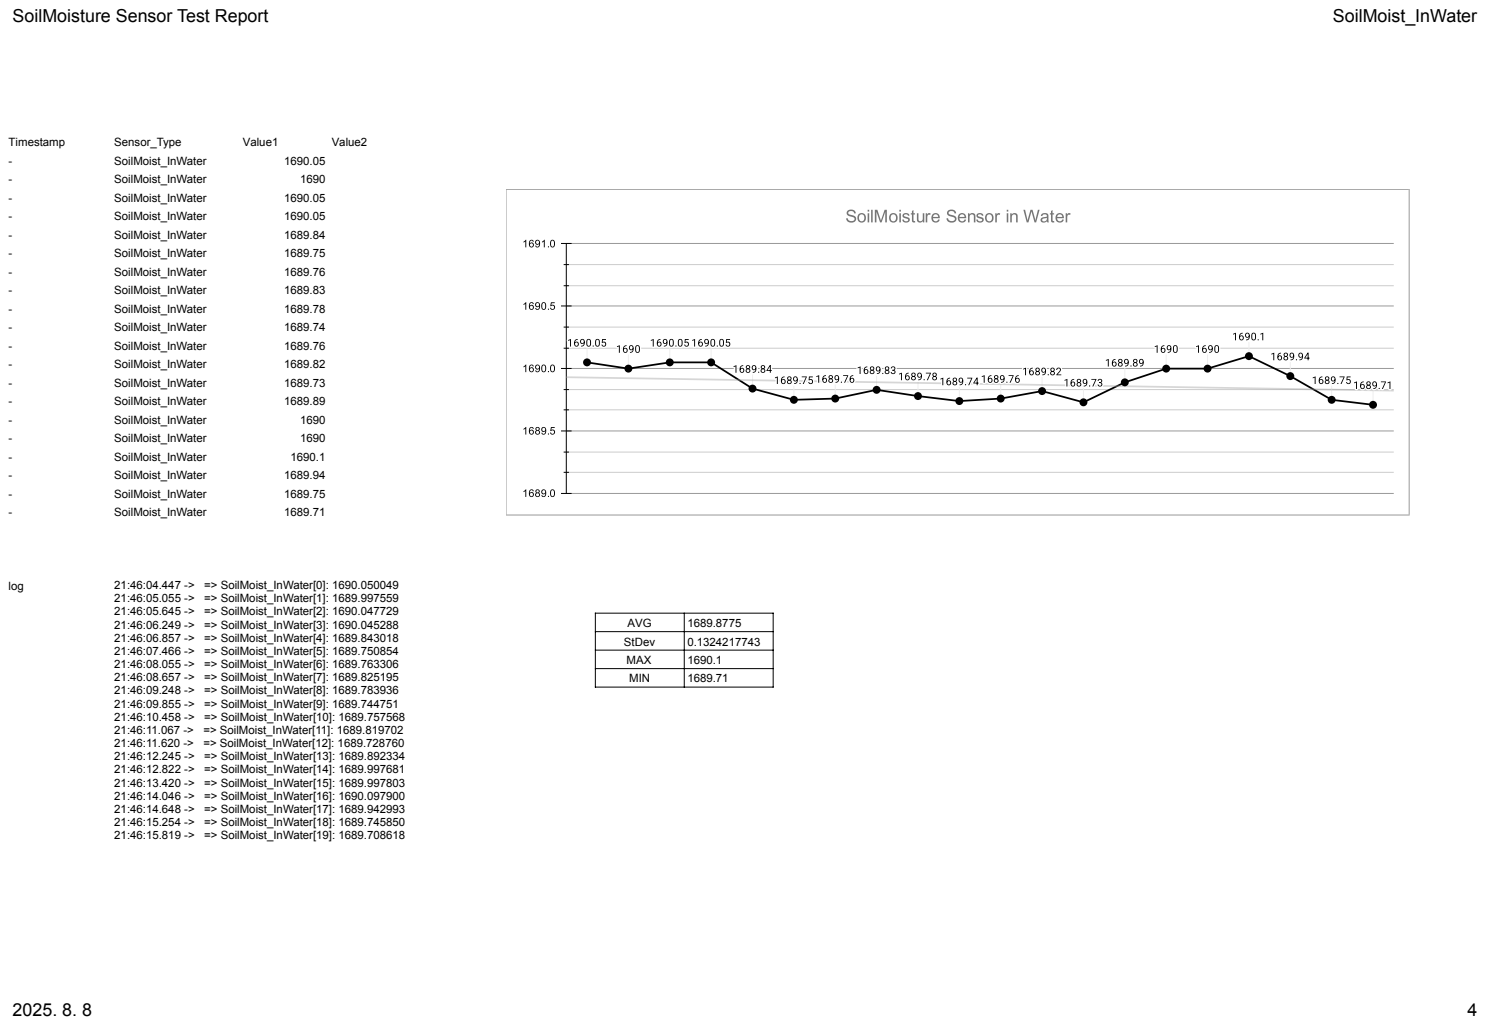
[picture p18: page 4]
Timestamp; Sensor_Type; Value1; Value2 -; SoilMoist_InWater; log; 21:46:04.447 -> => SoilMoist_InWater[0]: 1690.050049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

AVG | 1689.8775
StDev | 0.1324217743
MAX | 1690.1
MIN | 1689.71

SoilMoisture Sensor Test Report | SoilMoist_InAIR

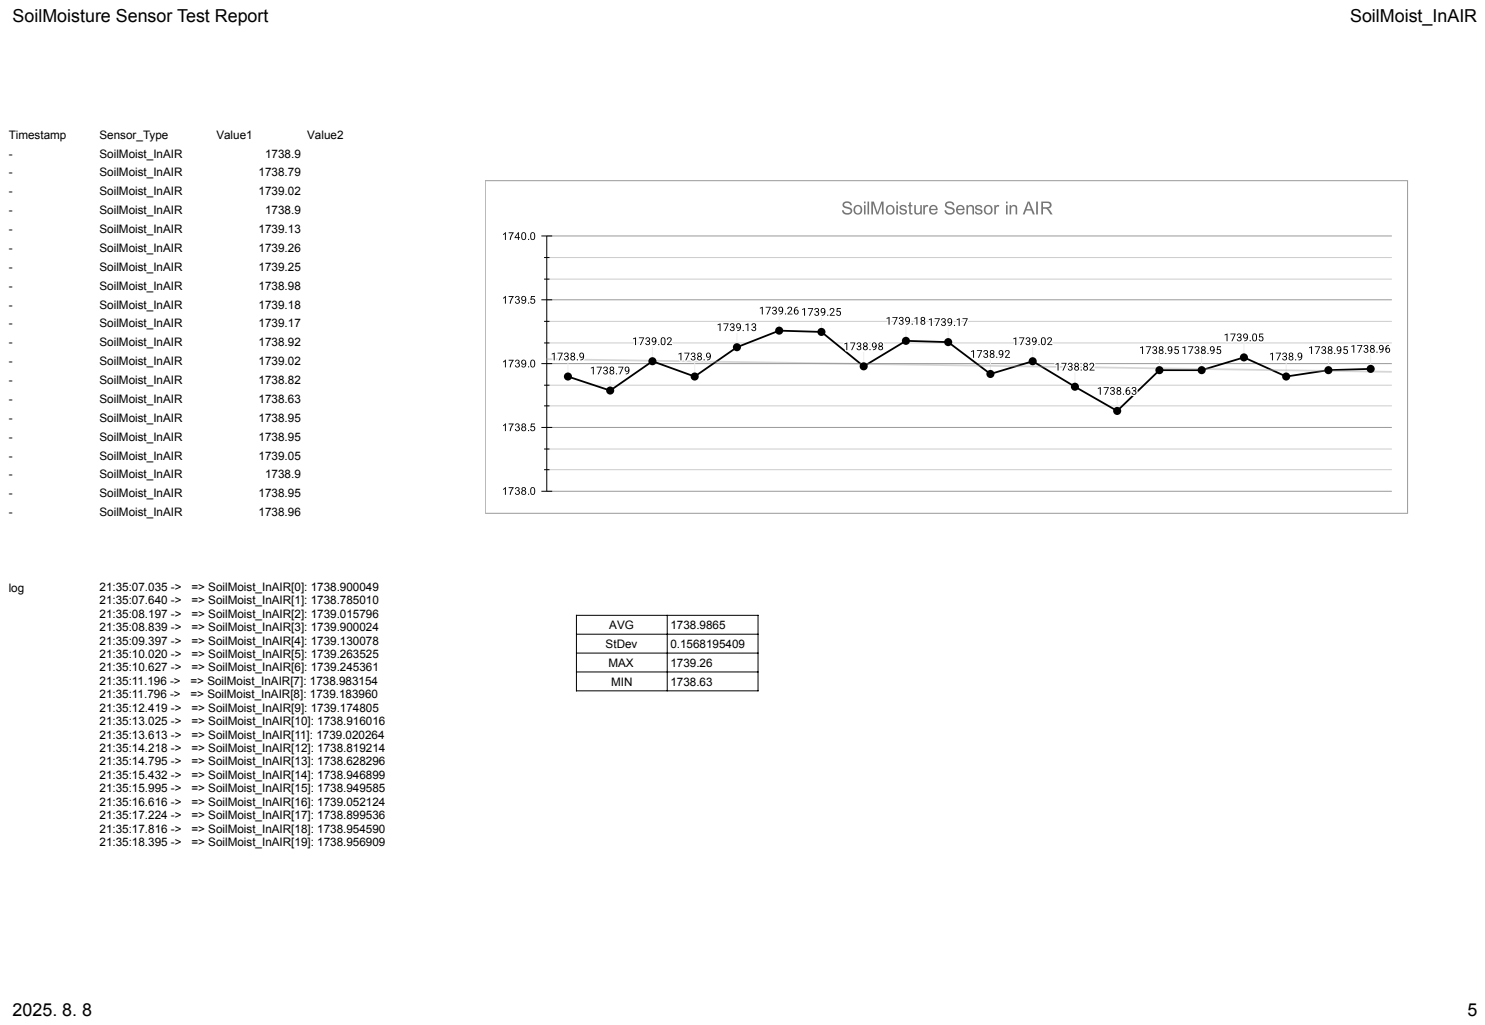
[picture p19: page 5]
Timestamp; Sensor_Type; Value1; Value2 -; SoilMoist_InAIR; log; 21:35:07.035 -> => SoilMoist_InAIR[0]: 1738.900049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

AVG | 1738.9865
StDev | 0.1568195409
MAX | 1739.26
MIN | 1738.63

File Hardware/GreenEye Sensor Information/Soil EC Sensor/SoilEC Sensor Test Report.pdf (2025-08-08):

SoilEC Sensor Test Report | Report

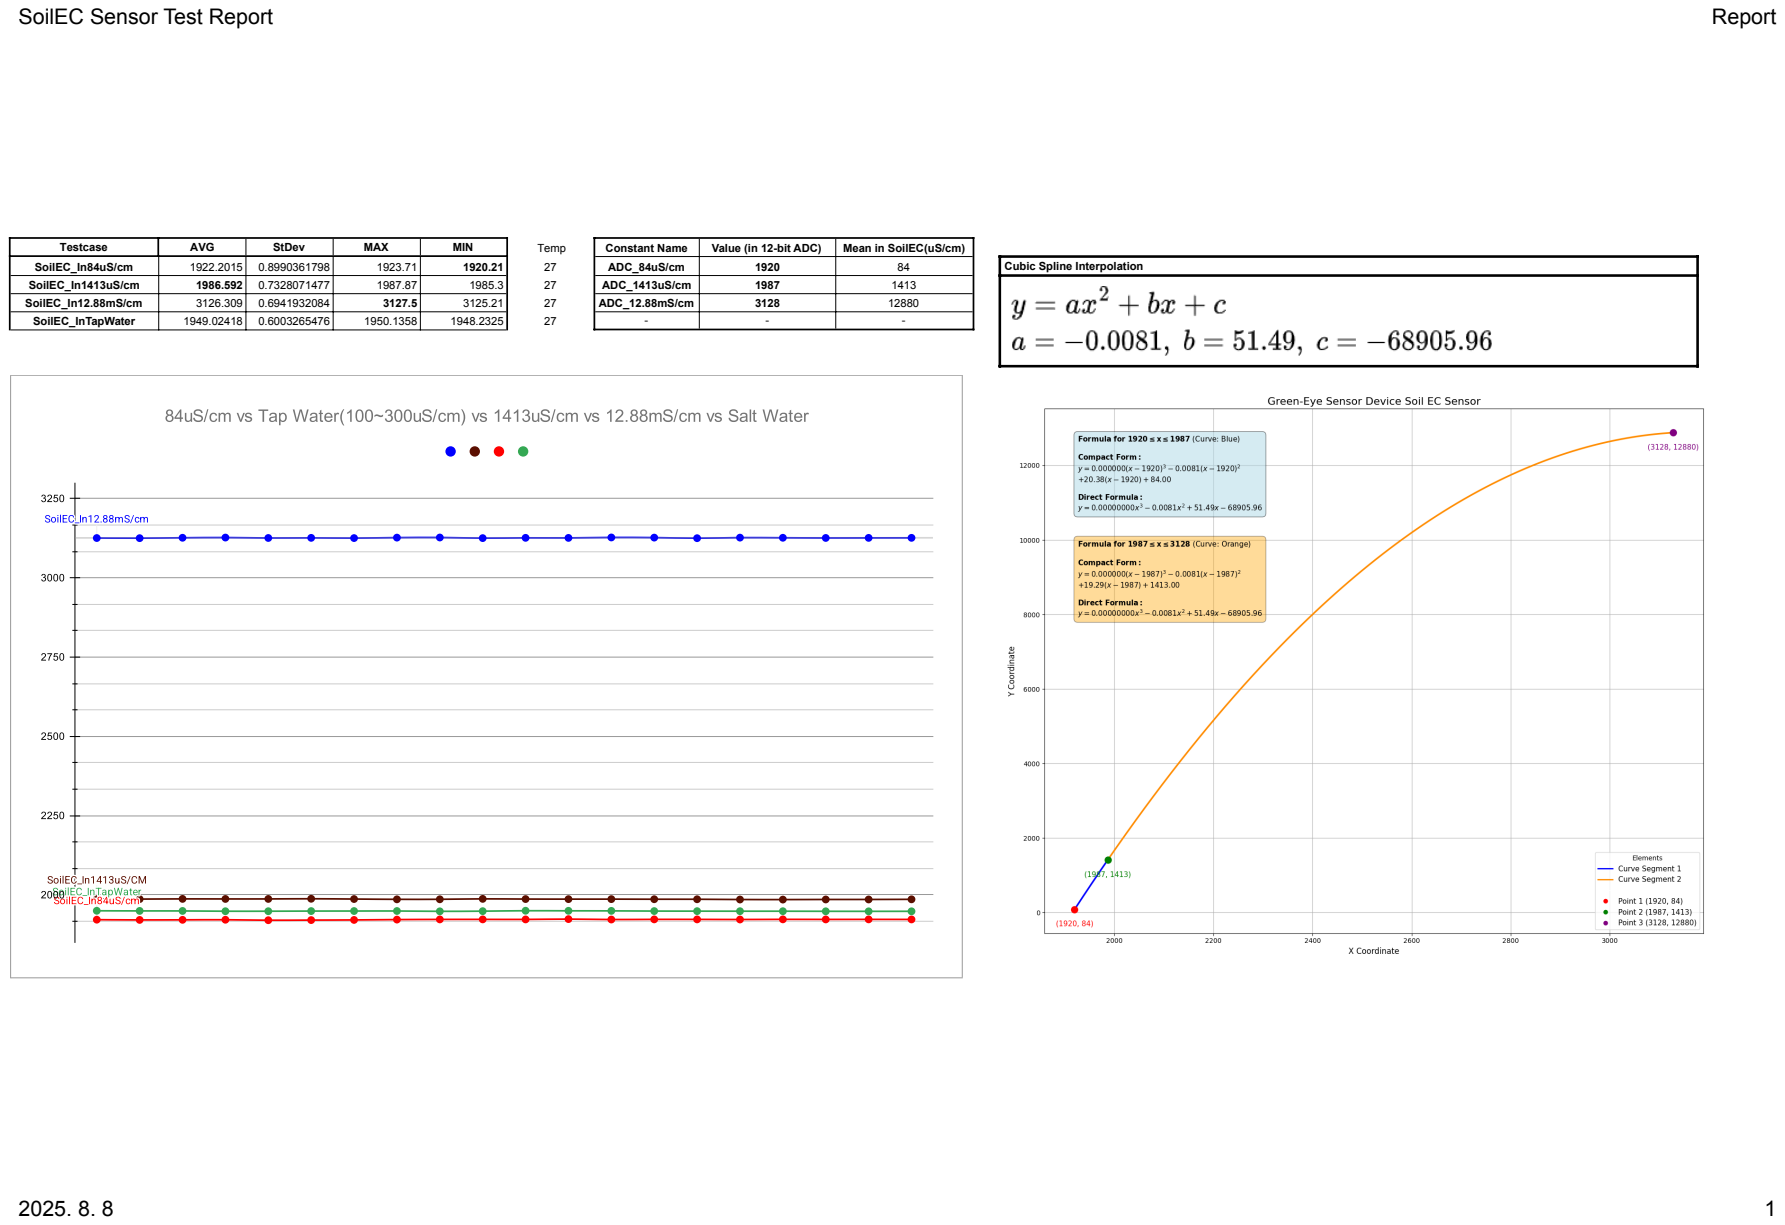
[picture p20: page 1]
Testcase; AVG; StDev; MAX; MIN; Temp; Constant Name; Value (in 12-bit ADC); Mean in SoilEC(uS/cm); SoilEC_In84uS/cm; ADC_84uS/cm; Cubic Spline Interpolation; SoilEC_In1413uS/cm; ADC_1413uS/cm; SoilEC_In12.88mS/cm; ADC_12.88mS/cm; SoilEC_InTapWater

SoilEC Sensor Test Report | SoilEC_In84uS/cm

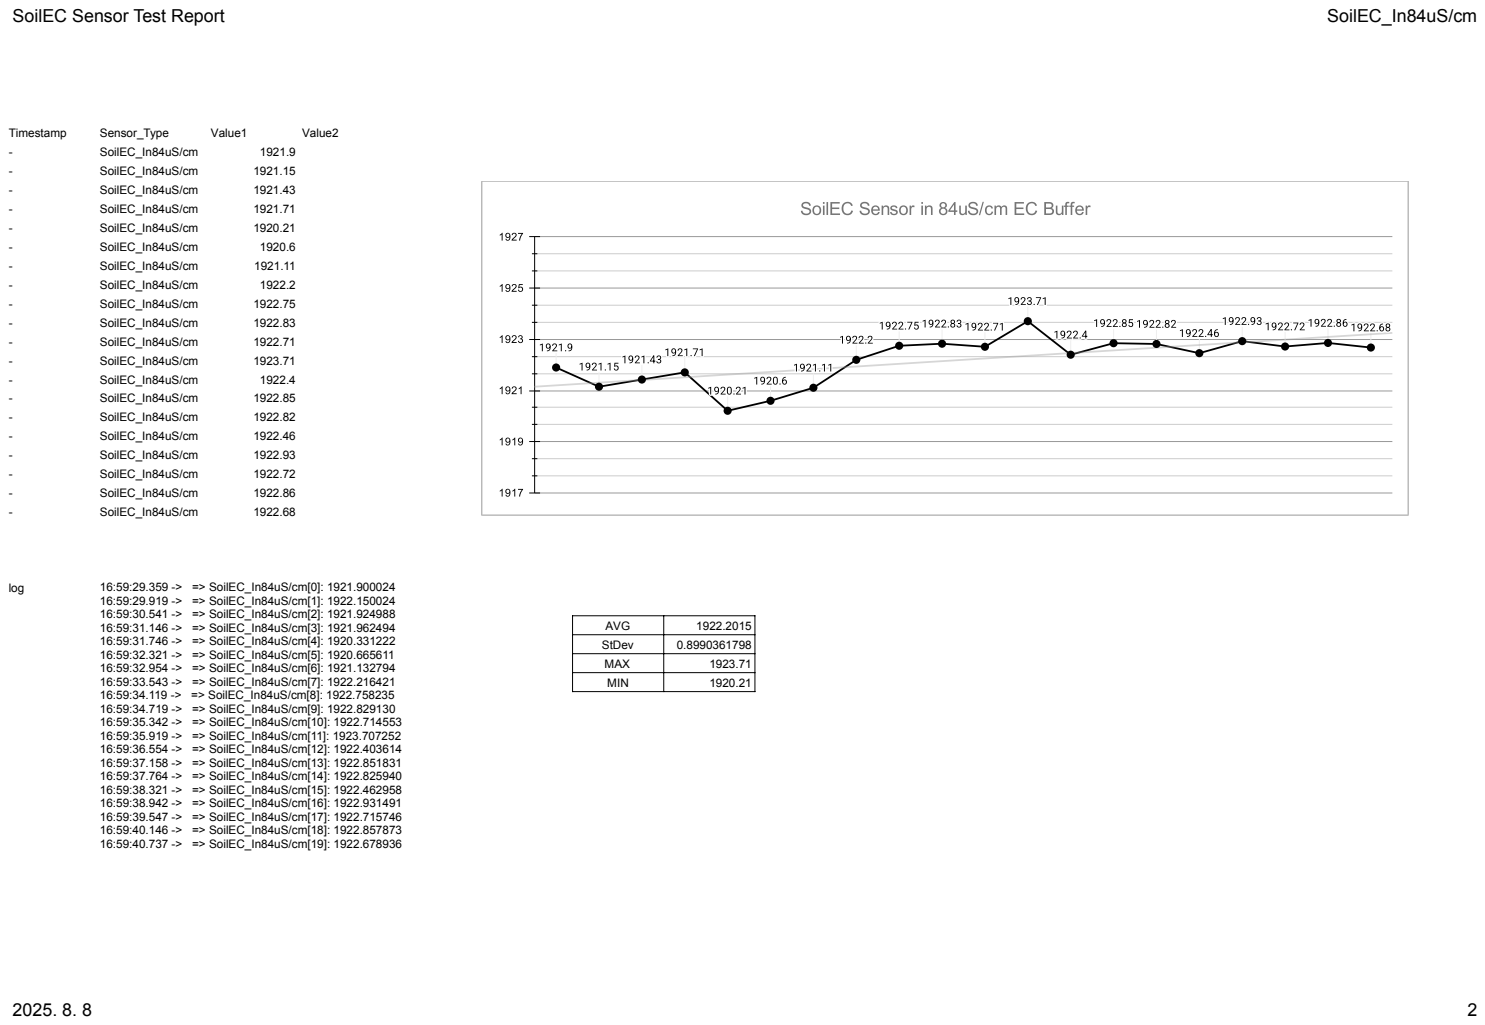
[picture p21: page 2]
Timestamp; Sensor_Type; Value1; Value2 -; SoilEC_In84uS/cm; log; 16:59:29.359 -> => SoilEC_In84uS/cm[0]: 1921.900024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

AVG | 1922.2015
StDev | 0.8990361798
MAX | 1923.71
MIN | 1920.21

SoilEC Sensor Test Report | SoilEC_In1413uS/CM

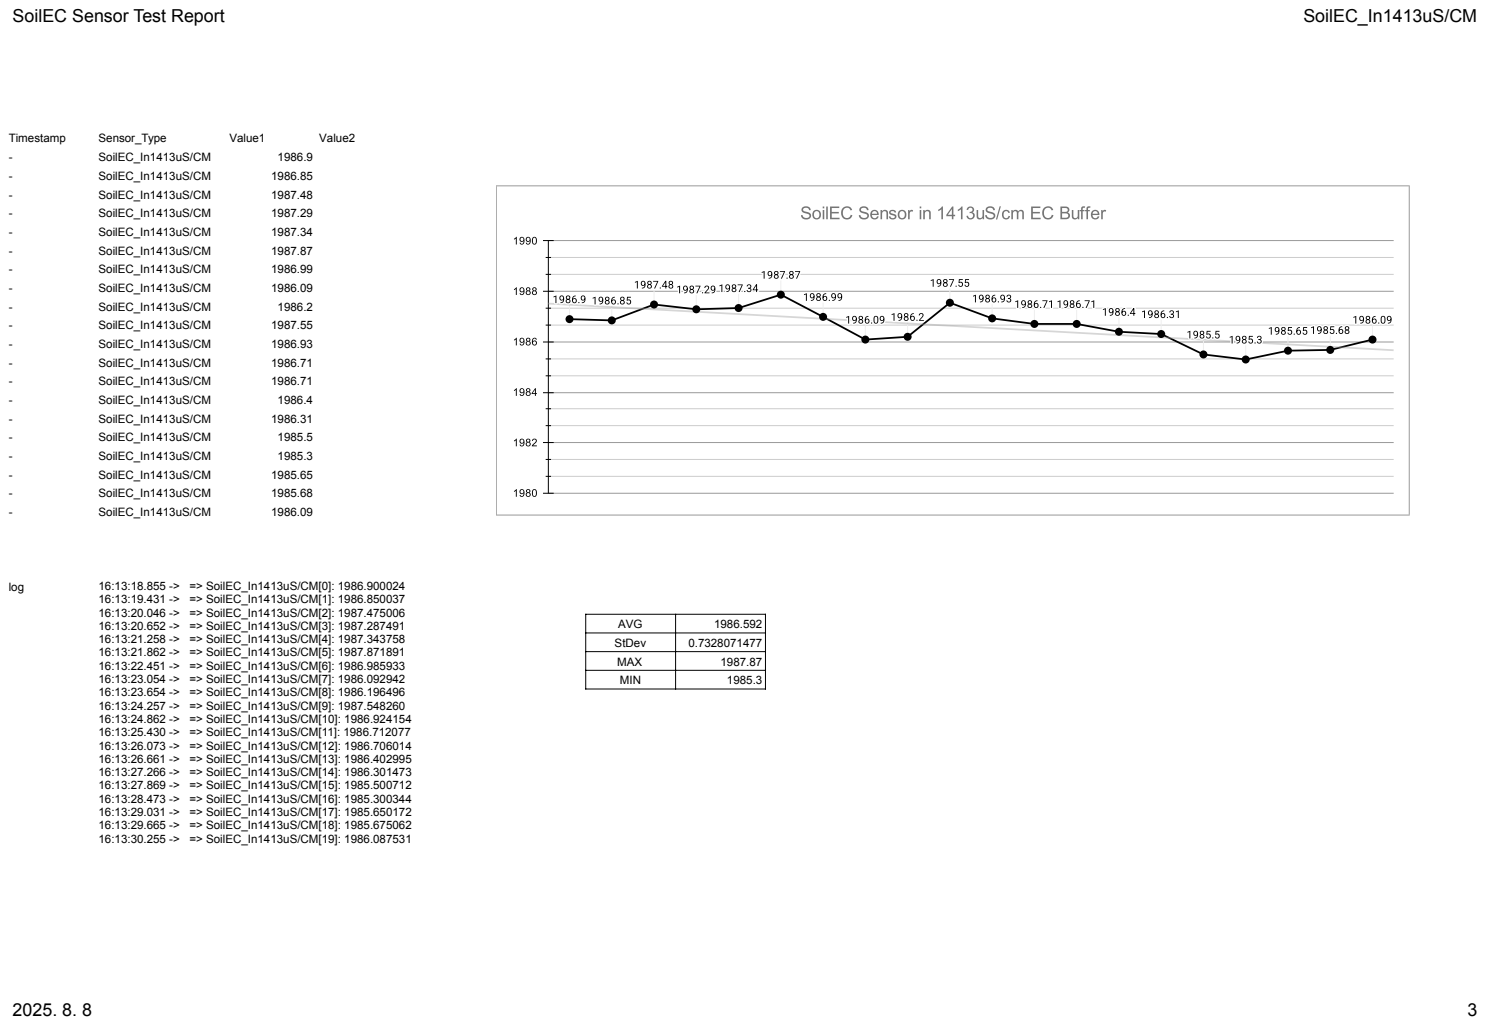
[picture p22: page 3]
Timestamp; Sensor_Type; Value1; Value2 -; SoilEC_In1413uS/CM; log; 16:13:18.855 -> => SoilEC_In1413uS/CM[0]: 1986.900024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

AVG | 1986.592
StDev | 0.7328071477
MAX | 1987.87
MIN | 1985.3

SoilEC Sensor Test Report | SoilEC_In12.88mS/cm

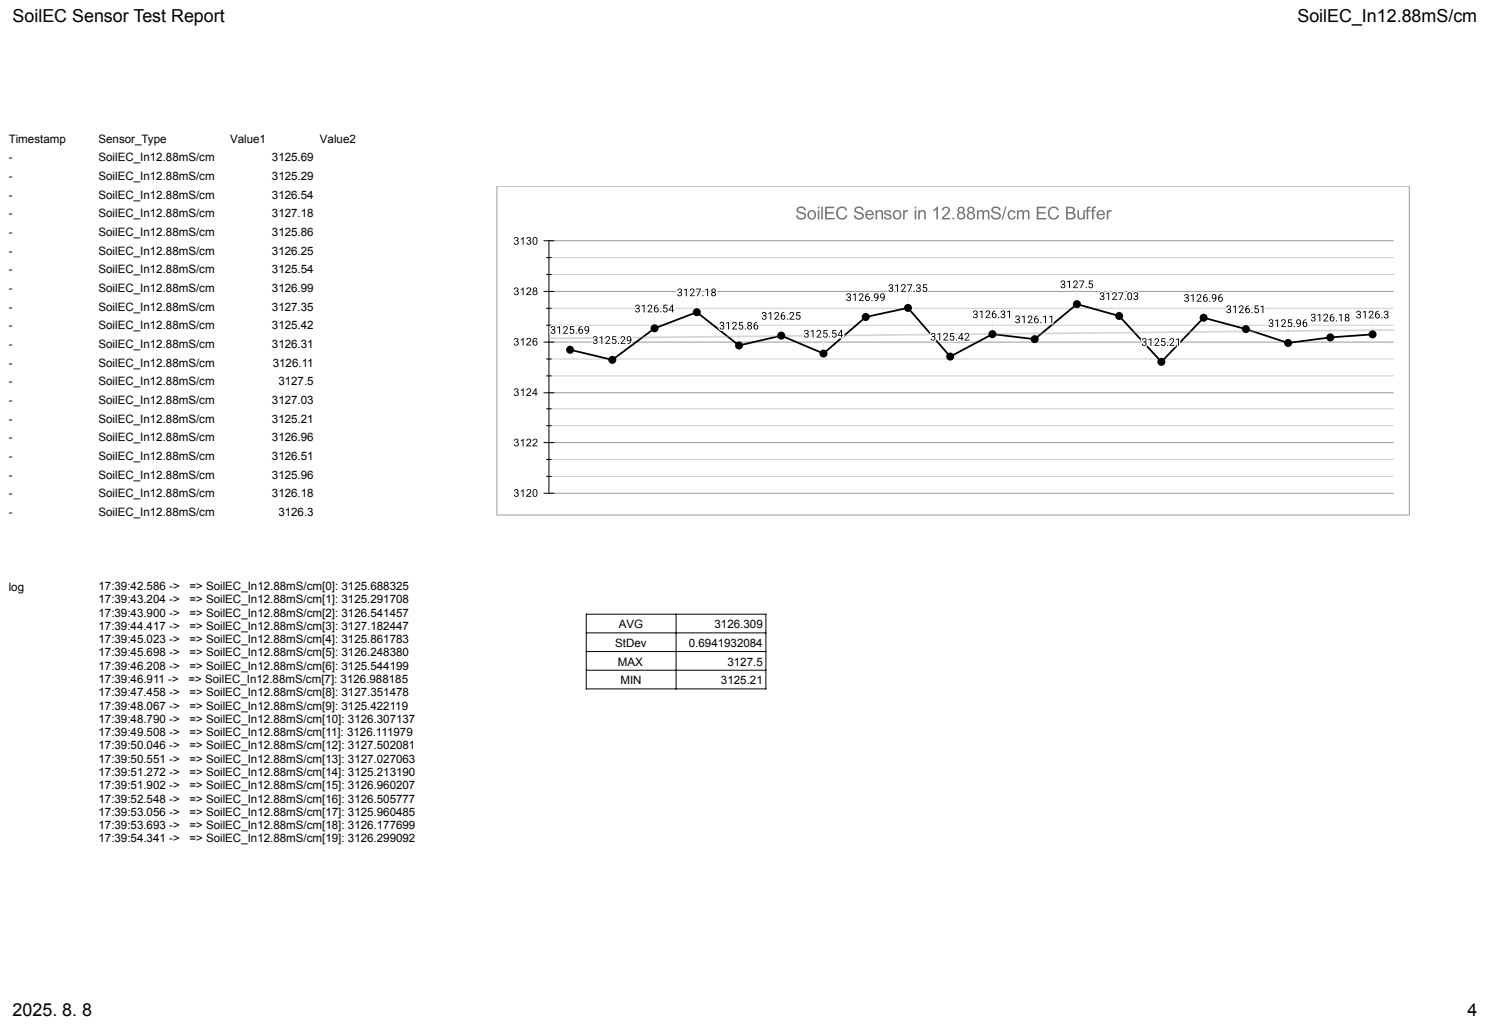
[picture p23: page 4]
Timestamp; Sensor_Type; Value1; Value2 -; SoilEC_In12.88mS/cm; log; 17:39:42.586 -> => SoilEC_In12.88mS/cm[0]: 3125.688325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

AVG | 3126.309
StDev | 0.6941932084
MAX | 3127.5
MIN | 3125.21

SoilEC Sensor Test Report | SoilEC_InTapWater

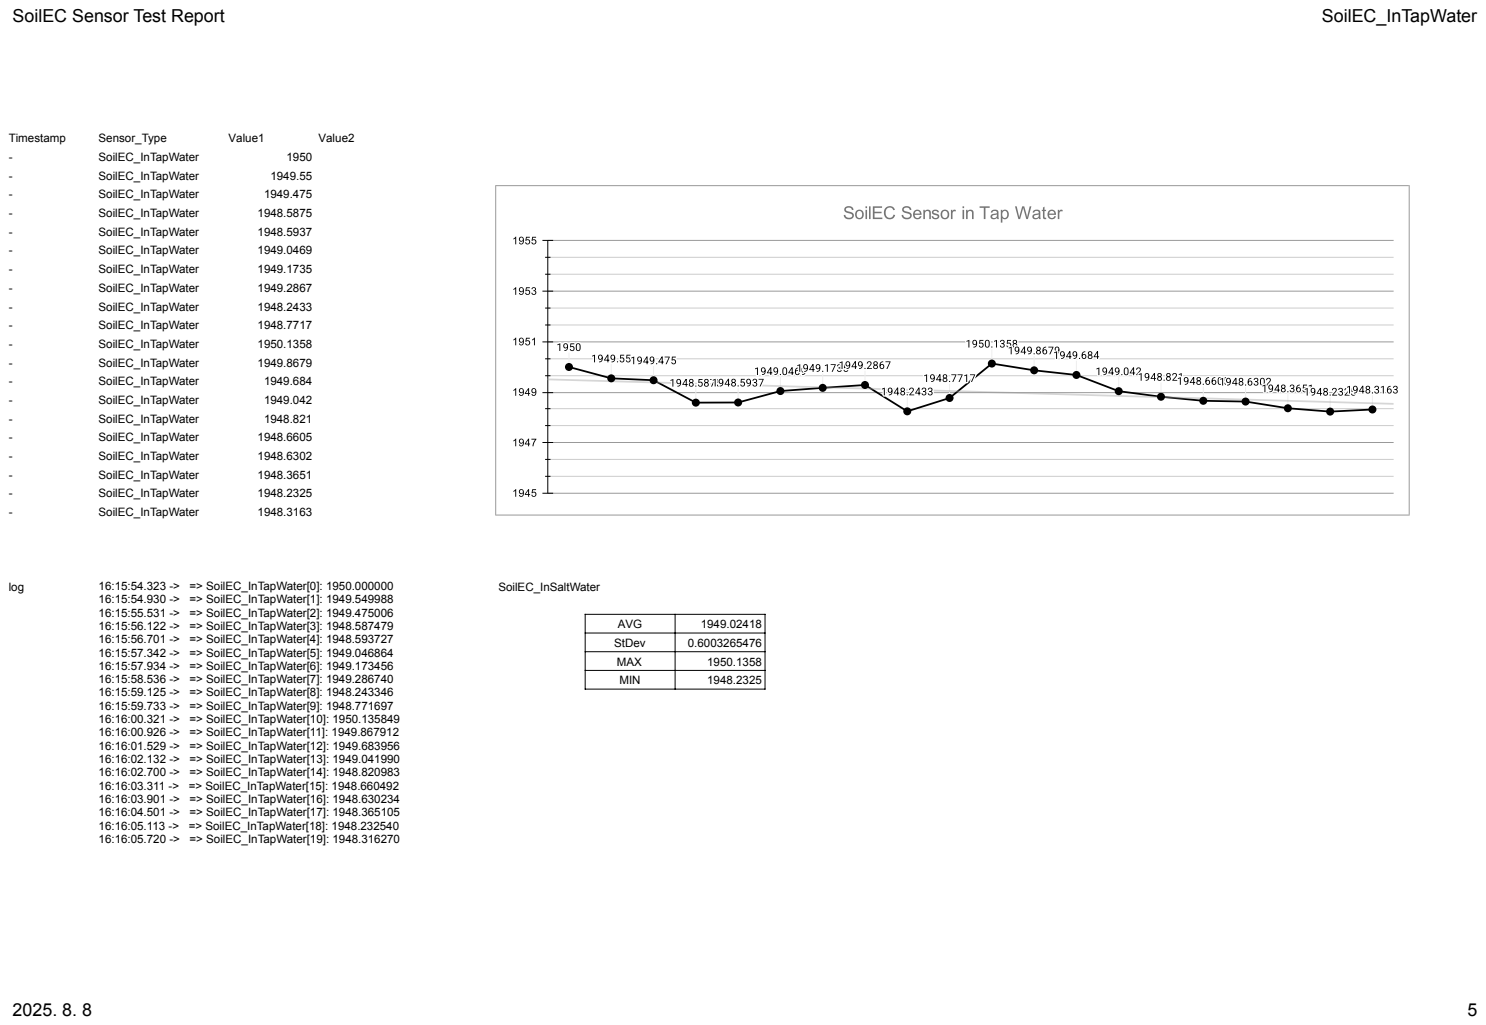
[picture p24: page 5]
Timestamp; Sensor_Type; Value1; Value2; SoilEC_InTapWater; log; 16:15:54.323 -> => SoilEC_InTapWater[0]: 1950.000000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

AVG | 1949.02418
StDev | 0.6003265476
MAX | 1950.1358
MIN | 1948.2325

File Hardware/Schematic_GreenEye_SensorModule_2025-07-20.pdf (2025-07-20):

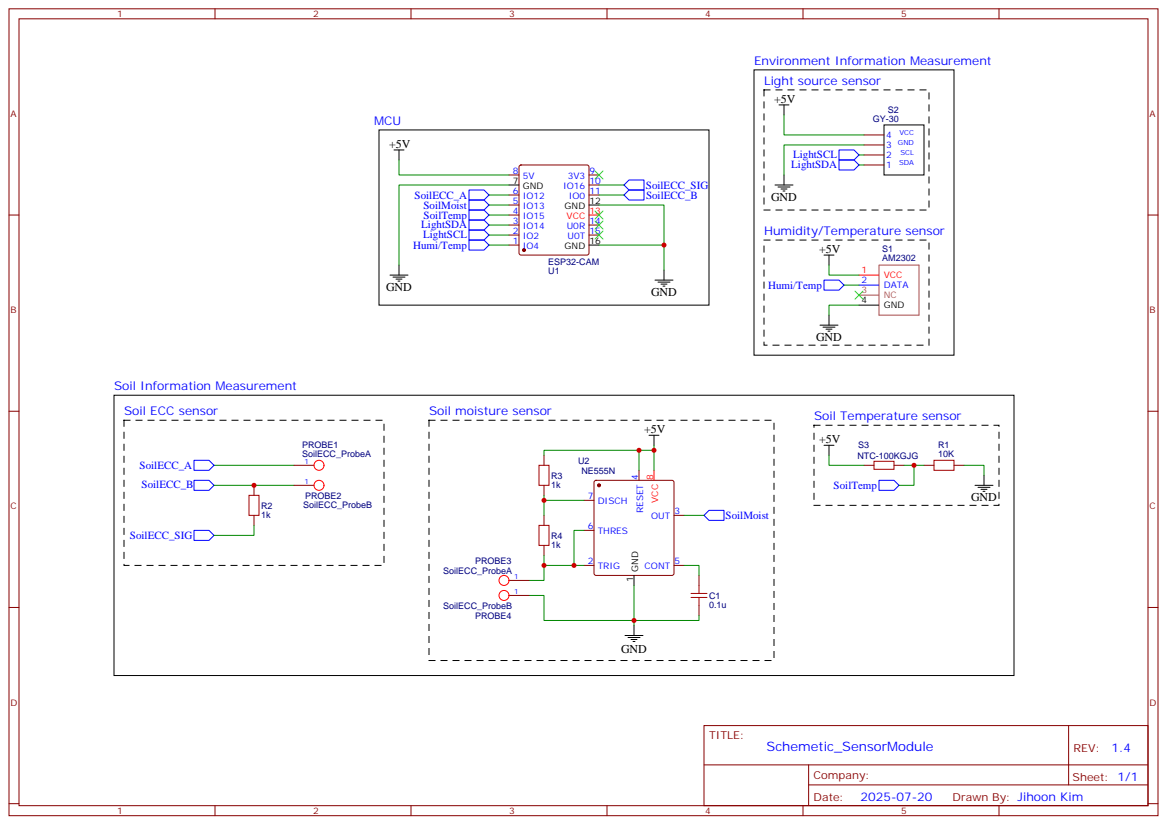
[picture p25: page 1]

Drawn By: Jihoon Kim

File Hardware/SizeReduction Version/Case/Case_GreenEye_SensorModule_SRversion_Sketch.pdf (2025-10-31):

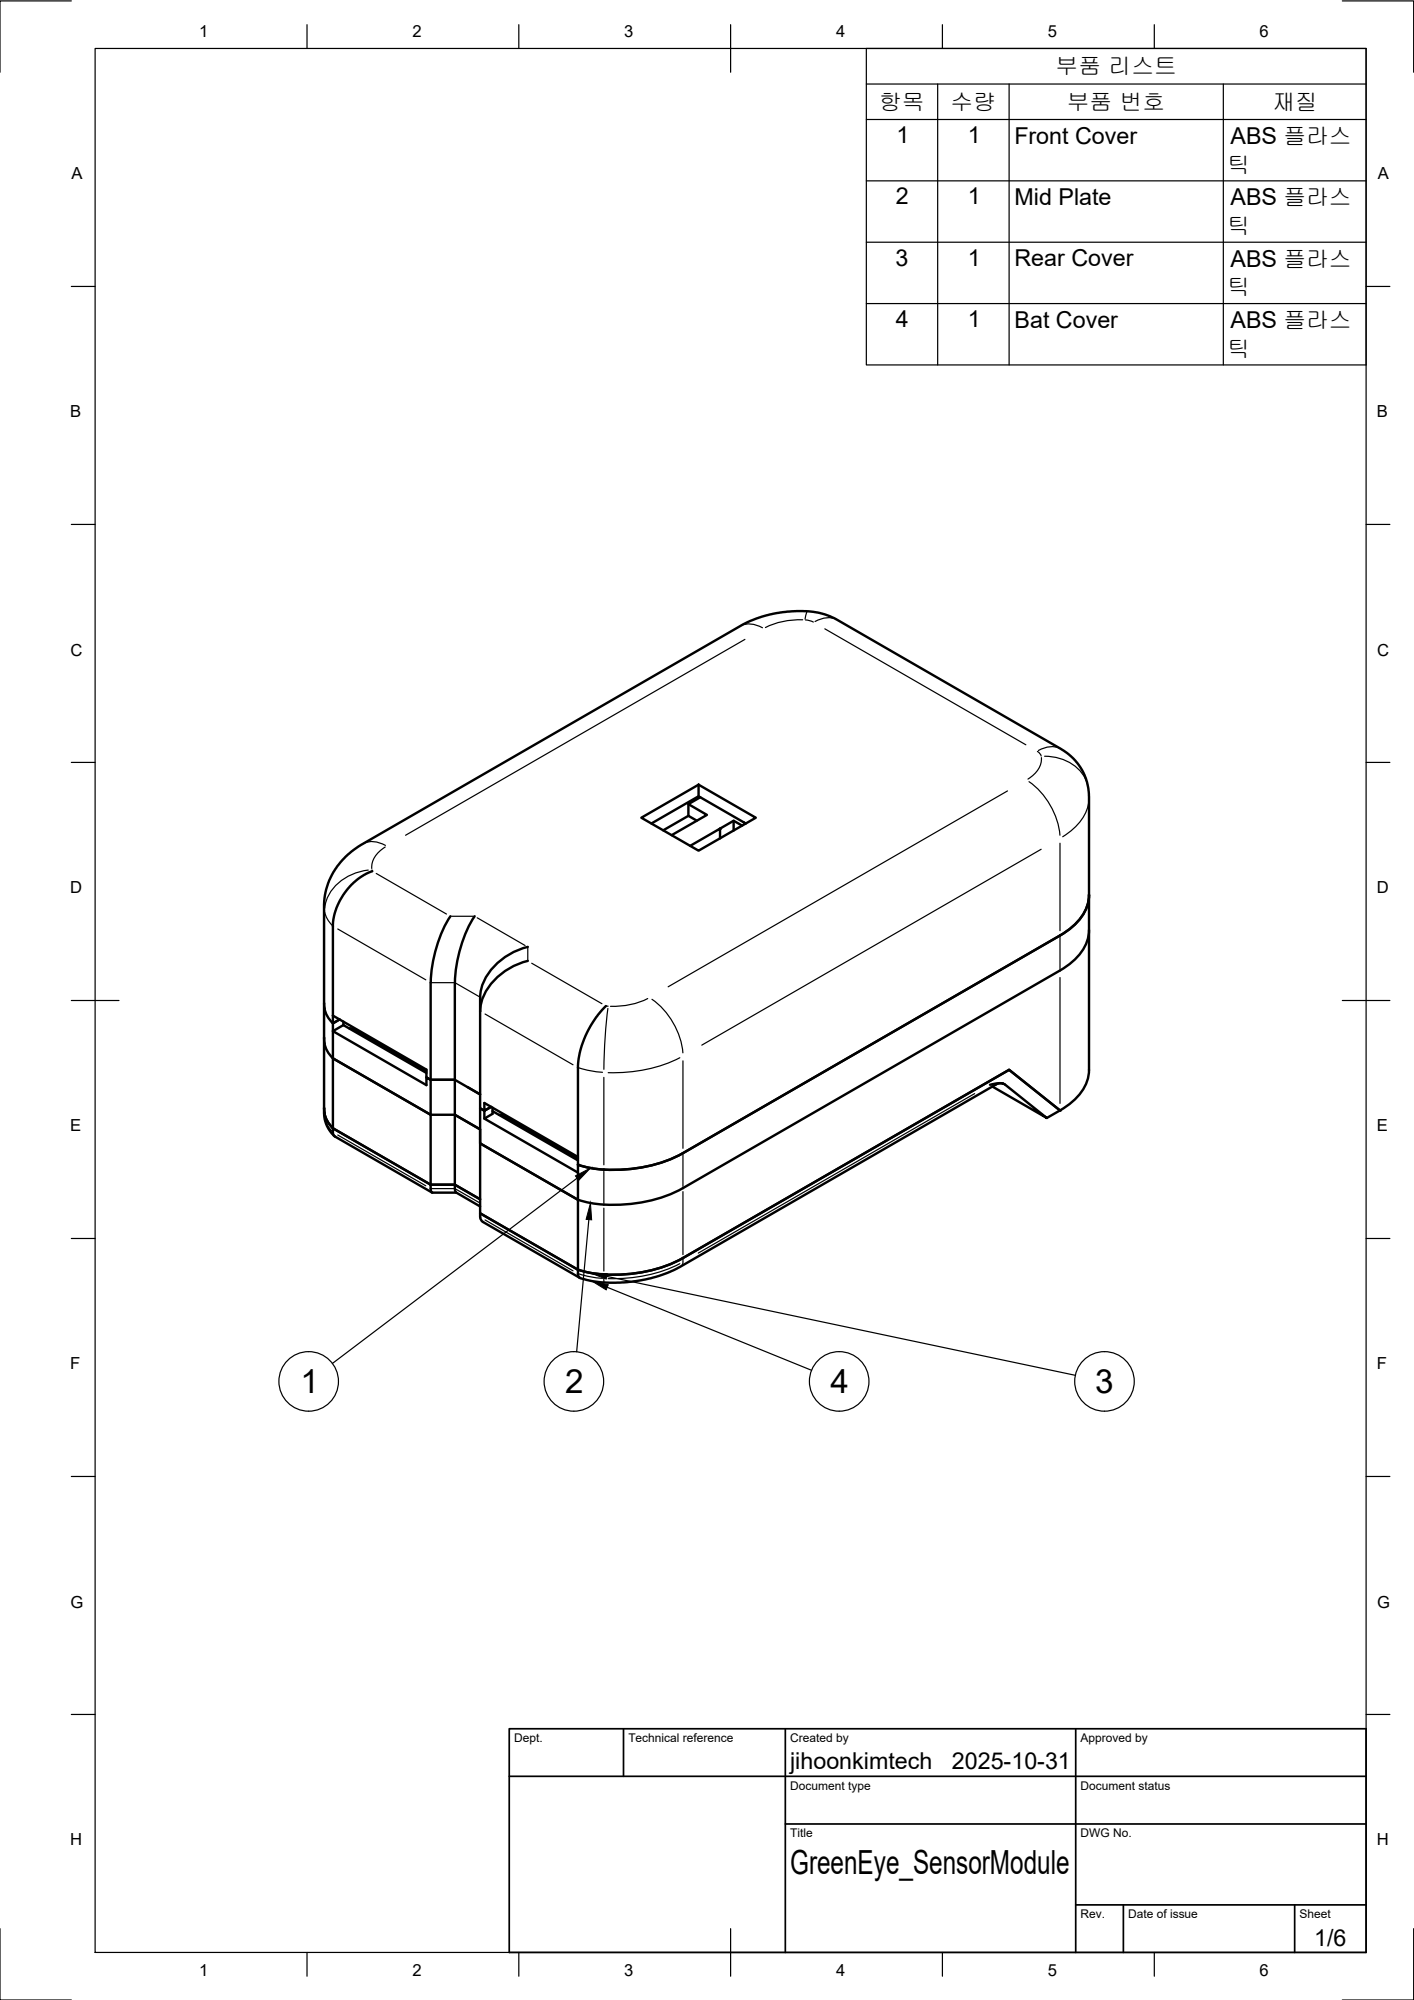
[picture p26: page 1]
부품 리스트

항목 | 수량 | 부품 번호 | 재질
1 | 1 | Front Cover | ABS 플라스 틱

2 | 1 | Mid Plate | ABS 플라스 틱

3 | 1 | Rear Cover | ABS 플라스 틱

4 | 1 | Bat Cover | ABS 플라스 틱

Dept. | Technical reference | Created by jihoonkimtech 2025-10-31 | Approved by

Document type | Document status

Title GreenEye_SensorModule | DWG No.

Rev. | Date of issue | Sheet


Dept. | Technical reference | Created by jihoonkimtech 2025-10-31 | Approved by

Document type | Document status


Dept. | Technical reference | Created by jihoonkimtech 2025-10-31 | Approved by

Document type | Document status

Front Cover


Dept. | Technical reference | Created by jihoonkimtech 2025-10-31 | Approved by

Document type | Document status

Mid Plate


Dept. | Technical reference | Created by jihoonkimtech 2025-10-31 | Approved by

Document type | Document status

Rear Cover

jihoonkimtech 49

Dept. | Technical reference | Created by 2025-10-31 | Approved by

Document type | Document status

Bat Cover



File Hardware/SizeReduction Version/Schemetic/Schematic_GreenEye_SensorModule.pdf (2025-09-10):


Drawn By: Jihoon Kim

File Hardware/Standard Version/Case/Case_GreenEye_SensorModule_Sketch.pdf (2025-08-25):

부품 리스트

항목 | 수량 | 부품 번호 | 재질
1 | 1 | Front Cover | 플라스틱
2 | 1 | Top Bat Cover | 플라스틱
3 | 1 | Back Cover | 플라스틱
4 | 1 | Side Bat Cover | 플라스틱

Dept. | Technical reference | Created by jihoonkimtech 2025-08-24 | Approved by

Document type | Document status

Title PCB_GreenEye_SensorModule | DWG No.

Rev. | Date of issue | Sheet


Dept. | Technical reference | Created by jihoonkimtech 2025-08-24 | Approved by

Document type | Document status


Dept. | Technical reference | Created by jihoonkimtech 2025-08-24 | Approved by

Document type | Document status

Front Cover

jihoonkimtech 78

Dept. | Technical reference | Created by 2025-08-24 | Approved by

Document type | Document status

Back Cover


Dept. | Technical reference | Created by jihoonkimtech 2025-08-24 | Approved by

Document type | Document status

Top BAT Cover


Dept. | Technical reference | Created by jihoonkimtech 2025-08-24 | Approved by

Document type | Document status

Side BAT Cover



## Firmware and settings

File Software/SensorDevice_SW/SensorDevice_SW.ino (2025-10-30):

#include "Camera.h"
#include "SensorIO_withExtLibs.h"
#include "PowerManager.h"
#include "MQTT.h"
#include "TimeManager.h"
#include <Preferences.h>
#include "mbedtls/base64.h"
#include "driver/rtc_io.h"
#include <ArduinoJson.h>
#include "freertos/FreeRTOS.h"
#include "freertos/task.h"
#include "freertos/queue.h"
#include <WiFi.h>
#include <AsyncTCP.h>
#include <ESPAsyncWebServer.h>
#include "Webpages.h"
#include "NetworkManager.h"

// === Main Debug Switch ===
#define MAIN_DEBUG 1 // set to 1 to enable detailed logs from this file, 0 to disable

#if MAIN_DEBUG == 1
  #define DEBUG_MAIN_PRINT(x) Serial.print(x)
  #define DEBUG_MAIN_PRINTLN(x) Serial.println(x)
#else
  #define DEBUG_MAIN_PRINT(x)
  #define DEBUG_MAIN_PRINTLN(x)
#endif

// --- Pin for entering Setup Mode ---
#define SETUP_BUTTON_PIN 2 // IO2 pin is used to enter setup mode

const int FLASH_PIN = 4;
const int LEDC_CHANNEL = 1; // LEDC Channel
const int LEDC_FREQ = 5000;   // PWM Freq
const int LEDC_RESOLUTION = 8; // 8bit Res

// --- rtos handles and queue ---
TaskHandle_t cameraTaskHandle = NULL;
TaskHandle_t backgroundTaskHandle = NULL;
QueueHandle_t commandQueue;

// --- command enum for rtos queue ---
enum Command { CMD_SEND_SENSORS, CMD_SEND_ALL };

// --- Forward declarations for callbacks and tasks ---
void sendSensorData();
void sendAllData();
void performOnDemandSensorRead();
void backgroundTask(void *parameter);

// --- Global Variables & Objects ---
RTC_DATA_ATTR int bootCount = 0; // a counter that survives deep sleep
int   battery_level    = 1; // holds the battery level percentage
float ambient_temp     = 2.0;  // holds ambient temperature
float ambient_humidity = 3.0; // holds ambient humidity
float light_intensity  = 4.0;  // holds light intensity
float soil_temp        = 5.0; // holds soil temperature
float soil_moisture    = 60.0; // holds soil moisture
float soil_ec          = 7.0; // holds soil electrical conductivity
String ccu_address     = "";   // holds the ccu address

// create async server and websocket objects
AsyncWebServer server(80);
AsyncWebSocket ws("/ws");

// create custom class objects
Preferences preferences; // create the preferences object for the flag
NetworkManager networkManager(&preferences);
TimeManager timeManager(MAIN_DEBUG); // create the time manager object
PowerManager powerManager(MAIN_DEBUG, &preferences); // create the power manager object
Camera camera; // create the camera object
SensorIO sensors( &battery_level, &ambient_temp, &ambient_humidity, &light_intensity, &soil_temp, &soil_moisture, &soil_ec, MAIN_DEBUG );
MQTTClient mqtt( &ccu_address, &powerManager, MAIN_DEBUG );

// --- Global flag for current mode ---
bool isSetupMode = false; // flag to determine the current operating mode
const unsigned long SETUP_MODE_TIMEOUT = 10 * 60 * 1000; // 10 minutes timeout for setup mode

// --- Wakeup Reason Handler ---
void handleWakeupReason(){
  esp_sleep_wakeup_cause_t wakeup_reason;
  wakeup_reason = esp_sleep_get_wakeup_cause();
  switch(wakeup_reason)
  {
    case ESP_SLEEP_WAKEUP_EXT0 : // in case of waking up from button press
      DEBUG_MAIN_PRINTLN("[INFO] Wakeup caused by external signal using RTC_IO");
      preferences.putBool("setup_mode", true); // set the flag to enter setup mode
      DEBUG_MAIN_PRINTLN("[ACTION] Rebooting into setup mode...");
      ESP.restart(); // restart to apply the mode change
      break;
    case ESP_SLEEP_WAKEUP_TIMER : // in case of waking up from timer
      DEBUG_MAIN_PRINTLN("[INFO] Wakeup caused by timer");
      break;
    default : // in other cases
      DEBUG_MAIN_PRINTLN("[INFO] Wakeup was not caused by deep sleep");
      break;
  }
}

// --- Action Functions (called by dashboard or MQTT) ---
void sendSensorData() {
    if (!WiFi.isConnected()) {
        DEBUG_MAIN_PRINTLN("[WARN] Not connected to WiFi, cannot send data.");
        return;
    }
    delay(250); // for stabilize
    sensors.readAllSensors(0);
    JsonDocument dataDoc;
    dataDoc["bat_level"] = battery_level;
    dataDoc["amb_temp"] = ambient_temp;
    dataDoc["amb_humi"] = ambient_humidity;
    dataDoc["amb_light"] = light_intensity;
    dataDoc["soil_temp"] = soil_temp;
    dataDoc["soil_humi"] = soil_moisture;
    dataDoc["soil_ec"] = soil_ec;
    String output;
    serializeJson(dataDoc, output);
    mqtt.loop();
    mqtt.publishData(output);
}

void sendCameraData() {
    if (!WiFi.isConnected()) return; // exit if not connected
    delay(250); // for stabilize
    DEBUG_MAIN_PRINTLN("[ACTION] Capturing high quality frame to send...");
    camera_fb_t* fb = camera.captureFrameForAnalyze(); // capture a high quality frame
    if (fb) { // if frame capture was successful
        DEBUG_MAIN_PRINTLN("[DEBUG] Frame captured successfully.");
        size_t output_len;
        mbedtls_base64_encode(NULL, 0, &output_len, fb->buf, fb->len);
        unsigned char *base64_buf = (unsigned char *)malloc(output_len + 1);
        if (base64_buf == NULL) {
            DEBUG_MAIN_PRINTLN("[ERROR] Failed to allocate memory for Base64 buffer!");
            camera.releaseFrameForAnalyze(fb);
            return;
        }
        if(mbedtls_base64_encode(base64_buf, output_len + 1, &output_len, fb->buf, fb->len) != 0) {
            DEBUG_MAIN_PRINTLN("[ERROR] Base64 encoding failed!");
            free(base64_buf);
            camera.releaseFrameForAnalyze(fb);
            return;
        }
        base64_buf[output_len] = '\0'; // ensure null termination
        JsonDocument dataDoc;
        dataDoc["plant_img"] = (char*)base64_buf;
        String output;
        serializeJson(dataDoc, output);
        mqtt.loop();
        mqtt.publishData(output); // publish the data
        free(base64_buf);
    } else {
        DEBUG_MAIN_PRINTLN("[ERROR] Failed to capture high quality frame for sending.");
    }
    camera.releaseFrameForAnalyze(fb); // release the frame buffer
}

void sendAllData() {
    sendSensorData();
    delay(100); // Small delay between sends
    sendCameraData();
}

void handleDataRequest() {
    DEBUG_MAIN_PRINTLN("[MQTT] Data request received from CCU.");
    sendSensorData(); // send sensor data in response
}

void handleConfig(JsonDocument& doc, PowerManager& pm) {
    DEBUG_MAIN_PRINTLN("[MQTT] Config received from CCU.");
    if (!doc["pwr_mode"].isNull()) { // if the json contains 'pwr_mode'
        const char* pwr_mode_str = doc["pwr_mode"]; // get the value as a string
        pm.setMode(pwr_mode_str[0]); // use the first character to set the mode
    }
    if (!doc["nht_mode"].isNull()) { // if the json contains 'nht_mode'
        bool nht_mode = doc["nht_mode"].as<bool>(); // get the boolean value
        pm.setNightMode(nht_mode); // set the new night mode
    }
}

void performOnDemandSensorRead() {
    DEBUG_MAIN_PRINTLN("[ACTION] On-demand sensor read initiated.");
    delay(100);
    sensors.begin(); // Initializes I2C and sensors
    delay(100);
    sensors.readAllSensors(0); // Read all sensor values in normal mode
    delay(100);
    sensors.endI2C(); // De-initialize I2C to free up pin 2
    DEBUG_MAIN_PRINTLN("[ACTION] On-demand sensor read complete. I2C released.");
}

// this function replaces placeholders in the html template
String processor(const String& var){
  if(var == "DASHBOARD_TITLE"){ return "GreenEye 센서단말<br>[" + networkManager.getHostname() + "]"; }
  if(var == "CURRENT_SSID"){
    preferences.begin("wifi-creds", true);
    String ssid = preferences.getString("ssid", "N/A");
    preferences.end();
    return ssid;
  }
  if(var == "CURRENT_CCU_ADDRESS"){
    preferences.begin("wifi-creds", true);
    String ccu = preferences.getString("ccu_address", "Not Set");
    preferences.end();
    return ccu;
  }
  return String();
}

// --- RTOS Task Functions ---
void onWsEvent(AsyncWebSocket *server, AsyncWebSocketClient *client, AwsEventType type, void *arg, uint8_t *data, size_t len) { 
    switch (type) { 
        case WS_EVT_CONNECT: 
            Serial.printf("[WebSocket] Client #%u connected from %s\n", client->id(), client->remoteIP().toString().c_str()); 
            // if this is the first client, resume the camera task 
            if (ws.count() == 1 && cameraTaskHandle != NULL) { 
                Serial.println("[ACTION] First WebSocket client connected, resuming camera task."); 
                vTaskResume(cameraTaskHandle); 
            } 
            break; 
        case WS_EVT_DISCONNECT: 
            Serial.printf("[WebSocket] Client #%u disconnected\n", client->id()); 
            // if the last client disconnected, suspend the camera task to save resources 
            if (ws.count() == 0 && cameraTaskHandle != NULL) { 
                Serial.println("[ACTION] Last WebSocket client disconnected, suspending camera task."); 
                vTaskSuspend(cameraTaskHandle); 
            } 
            break; 
        case WS_EVT_DATA: 
            // data event 
        break; 
        case WS_EVT_PONG: 
        case WS_EVT_ERROR: 
            // other events 
        break; 
    } 
} 

void cameraStreamTask(void *pvParameters) {
  while (1) {
    if (ws.count() > 0) {
      camera_fb_t *fb = camera.captureFrameForStream();
      if (fb) {
        ws.binaryAll(fb->buf, fb->len);
        camera.releaseFrameForStream(fb);
      }
    } else { vTaskDelay(pdMS_TO_TICKS(100)); }
    vTaskDelay(pdMS_TO_TICKS(333)); // fps
  }
}

void backgroundTask(void *parameter) {
    DEBUG_MAIN_PRINTLN("Background Task started on core 0.");
    static unsigned long buttonPressStartTime = 0;
    for (;;) {
        mqtt.loop();
        if (digitalRead(SETUP_BUTTON_PIN) == LOW) {
            if (buttonPressStartTime == 0) {
                buttonPressStartTime = millis();
            } else if (millis() - buttonPressStartTime > 3000) {
                DEBUG_MAIN_PRINTLN("[ACTION] Exiting Setup mode via button press. Restarting...");
                preferences.begin("device-state", false);
                preferences.putBool("setup_mode", false);
                preferences.end();
                ESP.restart();
            }
        } else {
            buttonPressStartTime = 0;
        }
        vTaskDelay(pdMS_TO_TICKS(20));
    }
}

void setup() {
    ledcSetup(LEDC_CHANNEL, LEDC_FREQ, LEDC_RESOLUTION);
    ledcAttachPin(FLASH_PIN, LEDC_CHANNEL);
    ledcWrite(LEDC_CHANNEL, 1);
    if(MAIN_DEBUG){
        Serial.begin(115200); // initialize serial communication
        delay(1000); // wait for serial monitor to open
    }
    if(!camera.begin()){ DEBUG_MAIN_PRINTLN("[ERROR] Failed to start camera"); } // initialize camera
    
    delay(2000); // wait for io pins to stabilize
    bootCount++; // increment the deep sleep wake-up counter
    DEBUG_MAIN_PRINT("[INFO] === Boot count: ");
    DEBUG_MAIN_PRINT(bootCount); DEBUG_MAIN_PRINTLN(" ===");

    preferences.begin("device-state", false); // initialize preferences for the mode flag
    powerManager.begin();
    handleWakeupReason(); // check why the device woke up
    bool enter_setup_flag = preferences.getBool("setup_mode", false); // check if the flag is set
    if (enter_setup_flag) {
        DEBUG_MAIN_PRINTLN("[DEBUG] SETUP MODE FLAG is HIGH.");
        isSetupMode = true; // enter setup mode
    }
    preferences.end();

        if (isSetupMode) {
        DEBUG_MAIN_PRINTLN("[MODE] SETUP MODE ACTIVATED.");
        ledcWrite(LEDC_CHANNEL, 0); delay(500); ledcWrite(LEDC_CHANNEL, 1); delay(500);
        ledcWrite(LEDC_CHANNEL, 0); delay(500); ledcWrite(LEDC_CHANNEL, 1); delay(500);
        ledcWrite(LEDC_CHANNEL, 0);

        networkManager.begin();
        sensors.begin();

        ws.onEvent(onWsEvent);
        server.addHandler(&ws);
        // setup all web server routes
        server.on("/", HTTP_GET, [](AsyncWebServerRequest *request) {
            DEBUG_MAIN_PRINTLN("[WebServer] Root ('/') page requested.");
            const char* content = WiFi.isConnected() ? DEVICE_STATUS_CONTENT : SETUP_FORM_CONTENT;
            // replace placeholders and send the page
            request->send_P(200, "text/html", DASHBOARD_MAIN_TEMPLATE, [content](const String& var) -> String {
                if (var == "PAGE_CONTENT") return FPSTR(content);
                return processor(var);
            });
        });
        server.on("/dashboard", HTTP_GET, [](AsyncWebServerRequest *request) {
            DEBUG_MAIN_PRINTLN("[WebServer] Dashboard ('/dashboard') page requested.");
            request->send_P(200, "text/html", DASHBOARD_MAIN_TEMPLATE, [](const String& var) -> String {
                if (var == "PAGE_CONTENT") return FPSTR(DASHBOARD_CONTENT);
                return processor(var);
            });
        });
        server.on("/api/sensors", HTTP_GET, [](AsyncWebServerRequest *request){
            DEBUG_MAIN_PRINTLN("[WebServer] API ('/api/sensors') data requested.");
            sensors.readAllSensors(0);
            
            JsonDocument dataDoc;
            dataDoc["bat_level"] = battery_level;
            dataDoc["pwr_mode"] = powerManager.getModeString();
            dataDoc["night_mode"] = powerManager.isNightModeEnabled() ? "ON" : "OFF";
            dataDoc["amb_temp"] = ambient_temp;
            dataDoc["amb_humi"] = ambient_humidity;
            dataDoc["amb_light"] = light_intensity;
            dataDoc["soil_temp"] = soil_temp;
            dataDoc["soil_humi"] = soil_moisture;
            dataDoc["soil_ec"] = soil_ec;
            
            String output;
     
            serializeJson(dataDoc, output);
            request->send(200, "application/json", output);
        });
        server.on("/camera", HTTP_GET, [](AsyncWebServerRequest *request){
            DEBUG_MAIN_PRINTLN("[WebServer] Camera ('/camera') page requested.");
            request->send_P(200, "text/html", WEBSOCKET_CAMERA_PAGE_HTML, processor);
        });
        server.on("/debug", HTTP_GET, [](AsyncWebServerRequest *request){
            DEBUG_MAIN_PRINTLN("[WebServer] Debug ('/debug') page requested.");
            request->send_P(200, "text/html", DASHBOARD_MAIN_TEMPLATE, [](const String& var) -> String {
                if (var == "PAGE_CONTENT") return FPSTR(DEBUG_PAGE_CONTENT);
                return processor(var);
            });
        });
        // handle form submissions
        server.on("/save", HTTP_POST, [](AsyncWebServerRequest *request){
            DEBUG_MAIN_PRINTLN("[WebServer] POST to '/save' received.");
            String getSsid = (request->hasParam("ssid", true)) ? request->getParam("ssid", true)->value():"";
            String getPw = (request->hasParam("password", true)) ? request->getParam("password", true)->value():"";
            String getCcuAddr = (request->hasParam("ccu_address", true)) ? request->getParam("ccu_address", true)->value():"";
            DEBUG_MAIN_PRINTLN("[INFO] Recieved Network datas");
            DEBUG_MAIN_PRINT("     SSID : "); DEBUG_MAIN_PRINTLN(getSsid);
            DEBUG_MAIN_PRINT("     PW : "); DEBUG_MAIN_PRINTLN(getPw);
            DEBUG_MAIN_PRINT("     CCU ADDR : "); DEBUG_MAIN_PRINTLN(getCcuAddr);

            preferences.begin("wifi-creds", false);
            preferences.putString("ssid", getSsid);
            preferences.putString("password", getPw);
            preferences.putString("ccu_address", getCcuAddr);
            preferences.end();
            request->send_P(200, "text/html", SUCCESS_PAGE_HTML);
            delay(1000); ESP.restart();
        });
        server.on("/forget", HTTP_POST, [](AsyncWebServerRequest *request){
            DEBUG_MAIN_PRINTLN("[WebServer] POST to '/forget' received.");
            preferences.begin("wifi-creds", false);
            preferences.remove("ssid");
            preferences.remove("password");
            preferences.remove("ccu_address");
            preferences.end();
            DEBUG_MAIN_PRINTLN("[INFO] Clear preference!");
            request->send_P(200, "text/html", FORGET_SUCCESS_PAGE_HTML);
            delay(1000); ESP.restart();
        });
        server.on("/save_ccu", HTTP_POST, [](AsyncWebServerRequest *request){
            DEBUG_MAIN_PRINTLN("[WebServer] POST to '/save_ccu' received.");
            preferences.begin("wifi-creds", false);
            if(request->hasParam("ccu_address", true)) preferences.putString("ccu_address", request->getParam("ccu_address", true)->value());
            preferences.end();
            request->send_P(200, "text/html", SUCCESS_PAGE_HTML);
            delay(1000);
            ESP.restart();
        });
        server.on("/set_power_mode", HTTP_POST, [](AsyncWebServerRequest *request){
            DEBUG_MAIN_PRINTLN("[WebServer] POST to '/set_power_mode' received.");
            if(request->hasParam("pwr_mode", true)) {
                String mode = request->getParam("pwr_mode", true)->value();
                powerManager.setMode(mode[0]);
            }
            request->redirect("/debug");
        });
        server.on("/set_night_mode", HTTP_POST, [](AsyncWebServerRequest *request){
            DEBUG_MAIN_PRINTLN("[WebServer] POST to '/set_night_mode' received.");
            if(request->hasParam("nht_mode", true)) {
                bool nightMode = request->getParam("nht_mode", true)->value().toInt() == 1;
                powerManager.setNightMode(nightMode);
            }
            request->redirect("/debug");
        });

        server.on("/send_sensor", HTTP_POST, [](AsyncWebServerRequest *request){
            DEBUG_MAIN_PRINTLN("[WebServer] POST to '/send_sensor' received.");
            sendSensorData(); // call the function to send sensor data
            request->redirect("/debug"); // redirect back to the debug page
        });

        server.on("/send_all", HTTP_POST, [](AsyncWebServerRequest *request){
            DEBUG_MAIN_PRINTLN("[WebServer] POST to '/send_all' received.");
            sendAllData(); // call the function to send all data (sensor + camera)
            request->redirect("/debug"); // redirect back to the debug page
        });

        server.begin(); // start server

        // create rtos tasks for setup mode
        xTaskCreatePinnedToCore(backgroundTask, "Background Task", 4096, NULL, 1, &backgroundTaskHandle, 0);
        xTaskCreatePinnedToCore(cameraStreamTask, "Camera Stream Task", 4096, NULL, 2, &cameraTaskHandle, 0);

        if (cameraTaskHandle != NULL) { 
            vTaskSuspend(cameraTaskHandle); 
        } 
    } else {
        DEBUG_MAIN_PRINTLN("[MODE] NORMAL MODE ACTIVATED."); 
        ledcWrite(LEDC_CHANNEL, 0); delay(500); ledcWrite(LEDC_CHANNEL, 1); delay(500);
        ledcWrite(LEDC_CHANNEL, 0);
        networkManager.begin();
        sensors.begin();
    }

    if (WiFi.status() == WL_CONNECTED) {
        DEBUG_MAIN_PRINTLN("[INFO] WiFi connected! setup logic start!");
        mqtt.onDataRequest(handleDataRequest);
        mqtt.onConfig(handleConfig);
        mqtt.begin();
        timeManager.begin();
        timeManager.updateTime();
    } else {
        if (!isSetupMode) {
             DEBUG_MAIN_PRINTLN("[ACTION] No WiFi in Normal Mode, entering setup mode on next boot.");
             preferences.begin("device-state", false);
             preferences.putBool("setup_mode", true);
             preferences.end();
             ESP.restart();
        }
    }

    // load ccu address from preferences into the global variable
    preferences.begin("wifi-creds", true); // open in read-only mode
    ccu_address = preferences.getString("ccu_address", "");
    preferences.end();

    if (MAIN_DEBUG && !ccu_address.isEmpty()) {
        DEBUG_MAIN_PRINT("[INFO] Loaded CCU Address: ");
        DEBUG_MAIN_PRINTLN(ccu_address);
    }
}

void loop() {
  if (isSetupMode) {
    // the loop is empty in setup mode because rtos tasks are running
    //vTaskDelay(pdMS_TO_TICKS(10));
  } else {
    // --- Normal Mode: Sense, Transmit, Sleep ---
    ledcWrite(LEDC_CHANNEL, 0);
    if (powerManager.isNightModeEnabled() && timeManager.isNightTime() && powerManager.getCurrentMode() != DEBUGGING) {
        DEBUG_MAIN_PRINTLN("[INFO] Night mode active. Woke up to check for MQTT updates.");
        if (WiFi.status() == WL_CONNECTED && mqtt.loop()) {
            DEBUG_MAIN_PRINTLN("[INFO] MQTT check complete.");
        } else {
            DEBUG_MAIN_PRINTLN("[WARN] Could not connect to WiFi/MQTT during night check.");
        }
        unsigned long sleep_duration_seconds = min(10UL * 60, timeManager.getSecondsUntil6AM());
        if (sleep_duration_seconds > 10) { 
            powerManager.enterDeepSleep(sleep_duration_seconds);
        } else {
            DEBUG_MAIN_PRINTLN("[INFO] Night mode period ending. Proceeding to normal operation.");
        }
    } 
    else {
        if (WiFi.status() == WL_CONNECTED) { 
          DEBUG_MAIN_PRINTLN("[INFO] WiFi Connected.");
          if (mqtt.loop()) { 
              DEBUG_MAIN_PRINTLN("[INFO] MQTT broker connected.");
              sendSensorData();
              if (powerManager.shouldSendCameraData(bootCount)) {
                  sendCameraData();
              }
              delay(2000);
              sensors.endI2C();
              powerManager.enterDeepSleep(powerManager.getSenseInterval());
          } else {
              DEBUG_MAIN_PRINTLN("\n[ERROR] Failed to connect to MQTT broker, entering setup mode on next boot.");
              preferences.putBool("setup_mode", true);
              ESP.restart();
          }
        } else {
          DEBUG_MAIN_PRINTLN("\n[ERROR] Failed to connect to WiFi, entering setup mode on next boot.");
          preferences.putBool("setup_mode", true);
          ESP.restart();
        }
    }
  }
}

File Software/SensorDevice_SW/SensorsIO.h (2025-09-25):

#pragma once // prevents multiple inclusion of the header file

#include <Wire.h> // for i2c communication
#include <cmath>  // for log() function

#define SENSOR_READ_RETRIES 5 // macro for sensor read retry count
#define SENSOR_AVG_COUNT 10   // macro for sensor averaging count

class SensorIO {
private:
    // i2c addresses
    const byte ADS1015_ADDRESS = 0x48; // i2c address for ads1015
    const byte AHT20_ADDR = 0x38;      // i2c address for aht20
    const byte GY302_ADDR = 0x23;      // i2c address for gy-302

    // pin definitions
    const int I2C_SDA_PIN = 14; // i2c sda pin
    const int I2C_SCL_PIN = 2;  // i2c scl pin
    const int SOIL_MOISTURE_EN_PIN = 15; // soil moisture sensor enable pin
    const int EC_PIN1 = 12; // ec probe pin 1
    const int EC_PIN2 = 13; // ec probe pin 2

    // pointers to external data variables
    int* _p_battery_level;
    float* _p_temp_ambient;
    float* _p_humidity;
    float* _p_light;
    float* _p_temp_soil;
    float* _p_moisture;
    float* _p_ec;
    bool _debug_enabled;

    // private helper to read from ads1015 with retries
    int16_t readADS1015(byte channel) {
        for (int i = 0; i < SENSOR_READ_RETRIES; i++) { // loop for retry attempts
            if (channel > 3) { return -1; } // ensure channel is valid
            uint16_t config = 0; // config variable
            config |= (1 << 15); // os: start a single conversion
            config |= ((4 + channel) << 12); // mux: set channel
            config |= (1 << 9);  // pga: gain 1, for +/- 4.096v range
            config |= (1 << 8);  // mode: single-shot mode
            config |= (4 << 5);  // dr: 1600 samples per second
            config |= 3;         // comp: comparator disabled
            
            Wire.beginTransmission(ADS1015_ADDRESS); // start transmission
            Wire.write(0x01); // point to config register
            Wire.write((config >> 8) & 0xFF); // write high byte
            Wire.write(config & 0xFF);   // write low byte
            Wire.endTransmission(); // end transmission
            delay(8); // wait for conversion
            
            Wire.beginTransmission(ADS1015_ADDRESS); // start transmission
            Wire.write(0x00); // point to conversion register
            Wire.endTransmission(); // end transmission
            
            Wire.requestFrom((uint8_t)ADS1015_ADDRESS, (size_t)2); // request 2 bytes
            if (Wire.available() == 2) { // if two bytes are received
                int16_t result = (Wire.read() << 8) | Wire.read(); // combine bytes
                return result >> 4; // return 12-bit result on success
            }
            delay(50); // short delay before retrying
        }
        if (_debug_enabled) Serial.printf("[SensorIO][ERROR] Failed to read ADC channel %d after %d retries.\n", channel, SENSOR_READ_RETRIES);
        return -1; // return -1 on failure to distinguish from 0
    }

    float getCalibratedEC(float adc_value) {
        const int NUM_CAL_POINTS = 10;
        const float adc_points[NUM_CAL_POINTS] = {
            200.0, 310.4, 574.8, 657.9, 931.5, 1069.7, 1112.9, 1158.6, 1425.7, 1489.7
        };
        const float ec25_points[NUM_CAL_POINTS] = {
            5.4, 23.9, 101.8, 167.3, 174.6, 426.5, 881.8, 1370.9, 2961.5, 5295.0
        };

        // Multi point linear interpolation
        for (int i = 0; i < NUM_CAL_POINTS - 1; i++) {
            if (adc_value >= adc_points[i] && adc_value <= adc_points[i+1]) {
                float x1 = adc_points[i];
                float y1 = ec25_points[i];
                float x2 = adc_points[i+1];
                float y2 = ec25_points[i+1];
                if (x1 == x2) return y1;
                return y1 + (adc_value - x1) * (y2 - y1) / (x2 - x1);
            }
        }

        if (adc_value < adc_points[0]) return ec25_points[0];
        else return ec25_points[NUM_CAL_POINTS - 1];
    }

public:
    SensorIO(
        int* p_battery_level,
        float* p_temp_ambient, float* p_humidity, float* p_light,
        float* p_temp_soil, float* p_moisture, float* p_ec,
        bool debug = false
    ) : _p_battery_level(p_battery_level),
        _p_temp_ambient(p_temp_ambient),
        _p_humidity(p_humidity),
        _p_light(p_light),
        _p_temp_soil(p_temp_soil),
        _p_moisture(p_moisture),
        _p_ec(p_ec),
        _debug_enabled(debug)
    {}

    void initI2C() {
        Wire.begin(I2C_SDA_PIN, I2C_SCL_PIN); // start i2c with specific pins
    }

    void endI2C() {
        Wire.end(); // releases the i2c bus and pins
    }
    
    void initTempHumiSensor() {
        Wire.beginTransmission(AHT20_ADDR); // start transmission to aht20
        Wire.write(0xBE); // send initialization command
        Wire.endTransmission(); // end transmission
        delay(100); // wait after initialization
    }

    void initSoilMoistureSensor() {
        pinMode(SOIL_MOISTURE_EN_PIN, OUTPUT); // set enable pin as output
        digitalWrite(SOIL_MOISTURE_EN_PIN, LOW); // start with sensor off
    }

    void initECSensor() {
        pinMode(EC_PIN1, INPUT); // set ec pins to input to keep them off
        pinMode(EC_PIN2, INPUT);
    }
    
    bool begin() {
        initI2C(); // initialize the i2c bus
        initTempHumiSensor(); // initialize the aht20 sensor
        initSoilMoistureSensor(); // set up the soil moisture pin
        initECSensor(); // set up the ec pins
        if (_debug_enabled) Serial.println("[SensorIO] Initialized."); // log initialization
        return true; // return success
    }

    // --- Individual Measurement Functions with Averaging, Raw Mode and Retries ---

    void readBatteryLevel(int rawMode) {
        if (!_p_battery_level) return; // check for valid pointer
        if (_debug_enabled) Serial.println("[SensorIO] Reading Battery Level...");
        long total = 0; // use long for accumulator
        int valid_readings = 0; // count valid readings
        for (int i = 0; i < SENSOR_AVG_COUNT; i++) { // loop 10 times
            int16_t adcValue = readADS1015(2); // read from adc channel 2 for bat_level
            if (adcValue >= 0) { // process valid readings (including 0)
                total += adcValue; // add to total
                valid_readings++; // increment count
            }
            delay(10); // short delay between readings
        }

        if (valid_readings == 0) { 
            if (_debug_enabled) Serial.println("[SensorIO][ERROR] Failed to get any valid battery readings.");
            *_p_battery_level=0; 
            return; 
        }
        
        int16_t avgAdcValue = total / valid_readings; // calculate average adc value
        if (_debug_enabled) Serial.printf("  [DEBUG] Battery Average ADC: %d\n", avgAdcValue);
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

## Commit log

2025-07-25 Update 2.5V
    Refine designator, Change Power net's name
2025-07-26 Update v2.6
    Change Soil Temp sensor's symbol
2025-07-26 Upload gerber file for v2.6
    v2.6
    [Drill_NPTH_Through.DRL, Drill_PTH_Through.DRL, Drill_PTH_Through_Via.DRL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]
2025-07-26 Upload BOM list for v2.6
    [BOM_GreenEye_SensorModule.csv]
2025-07-26 Upload PCB 3D priview
2025-07-26 Fix board outline
    [Drill_NPTH_Through.DRL, Drill_PTH_Through.DRL, Drill_PTH_Through_Via.DRL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]
2025-07-26 Upload 2D drawing file for v2.6
    [PCB_GreenEye_SensorModule.dxf]
2025-07-29 Upload BOM's price list
    [PriceList_GreenEye_SensorModule.csv]
2025-07-30 Upload test programs
    for Light, Soil Temp, Temp/Humi Sensor
2025-07-30 Add Software/SensorDevice_SW/.vscode
2025-08-01 Upload camera test program
2025-08-02 Update v3.0
    Add battery capacity check circuit
    Soil sensors integrated into I2C ADC
    Adding terminals for debug and upload
2025-08-02 Apply v3.0
    [Drill_NPTH_Through.DRL, Drill_PTH_Through.DRL, Drill_PTH_Through_Via.DRL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]
2025-08-03 Update soil moisture sensor version
2025-08-04 Update separated WiFi/ADC2
    Avoid collisions with ADC2
    [AnalogData_Sender_SoilMoist.ino]
2025-08-04 Update add sensor stabilizing process
2025-08-05 Hide apps script url
    Delete the script because the script URL is exposed ( my mistake :( )
    [AnalogData_Sender_SoilMoist.ino]
2025-08-05 Upload soil EC sensor version
2025-08-05 Upload sensor test reports
    for custom soil sensors
2025-08-09 Update sensor dashboard
2025-08-09 Update camera tuning setting
2025-08-09 Update available camera stream at dashboard
2025-08-14 Upload SD Sensor I/O Manual
2025-08-15 Update apply sensor I/O manual
2025-08-18 Update combine sensor librarys
2025-08-18 Update all sensors IO function
2025-08-19 Update power mode management library
2025-08-19 Update comments, fix type error
    [MQTT.h]
2025-08-24 Upload case sketch
2025-08-24 Upload case stl files
    [Back Cover.stl, Front Cover.stl, Side Bat Cover.stl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]
2025-08-25 Update Top Bat Cover
    make gap loosely
    [Top Bat Cover.stl]
2025-08-27 Fix wifi connection error
    [SensorDevice_SW.ino]
2025-08-27 Update enable to wake up using button
2025-08-27 Fix setup mode button error
    using pull-up
    [SensorDevice_SW.ino]
2025-08-29 Update v3
    compatible with the latest version library
    fix toggle setup mode error
    [SensorDevice_SW.ino]
2025-08-29 Fix initialize subsystems based on the selected mode
    [SensorDevice_SW.ino]
2025-08-29 Fix cannot escape setup mode using button
    [SensorDevice_SW.ino]
2025-08-29 Fix camera initializing timing, comments
    [SensorDevice_SW.ino]
2025-08-29 Update camera setting
2025-08-29 Update v4
    change setup mode button pin num
    change camera init timing
    enable sensing function
2025-08-29 Fix wrong value, order
    [SensorsIO.h]
2025-08-30 Fix useless serial debug msg
    [Camera.h]
2025-09-01 Update SensorIO's extra version for using external libs
2025-09-01 Update enable to check sensor value in setup mode
2025-09-10 Fix only sensor data update in dashboard page
2025-09-10 Fix delete wrong pin mode setup
    [SensorDevice_SW.ino]
2025-09-10 Update change the file structure for versioning
    [Back Cover.stl, Front Cover.stl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]
2025-09-10 Upload Size Reduction Version PCB
    [Drill_NPTH_Through.DRL, Drill_PTH_Through.DRL, Drill_PTH_Through_Via.DRL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]
2025-09-21 Fix wrong gain, wrong channel selection
    [SensorIO_withExtLibs.h, SensorsIO.h]
2025-09-24 Update & Fix change code structure, stabilize web server
    Delete Dashboard,h and Add NetworkManager.h, Webpages.h
    Fix templete errors, pointer errors
    [MQTT.h, SensorDevice_SW.ino]
2025-09-25 Fix enable virtical flip
    [Camera.h]
2025-09-25 Fix change delay to TaskDelay
    [MQTT.h]
2025-09-25 Fix change calibration value
    [SensorsIO.h]
2025-10-30 Fix: lower frame rate for stability
    [SensorDevice_SW.ino]
2025-10-31 Update: case file(sketch, stl) upload
    [Bat Cover.stl, Front Cover.stl, Mid Plate.stl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]
2025-10-31 Update: price list
    [PriceList_GreenEye_SensorModule.csv]
